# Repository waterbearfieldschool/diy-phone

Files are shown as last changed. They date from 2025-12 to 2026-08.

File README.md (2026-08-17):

# diy-phone

A from-scratch mobile phone: nRF52840 + SIM7600 cellular + e-ink display +
I2C keyboard. Texts, calls, contacts, a dial pad, and a serial console.

**Current version: [`v61e/`](v61e/) — see its [README](v61e/README.md).**

Each `vNN/` directory is a complete firmware snapshot; the version number
only ever goes up, so the highest one is the newest. Directories with an
`e` suffix (v45e onward) target the e-ink display; earlier versions drove
a 240x240 TFT.

The defining design idea of the current line: **all-driven partial
refreshes**. The SSD1681 only drives pixels that differ from its stored
"previous image" — and undriven pixels are what fade and ghost on this
panel. So the firmware writes each frame to the controller's current RAM
plane and the frame's *inverse* to the previous-image plane: every pixel
compares as changed, every pixel gets driven, and the panel delivers
crisp text on every quiet update — no fading, no ghosts, and no blinking
at all during use (full refreshes survive only at boot and as a rare
idle panel-care cycle). The full story, including the failed
approaches that mapped the panel's behavior, is in the v61e README.

Waypoints in the history: `v41` (the TFT firmware, restructured into
modules), `v44` (address book, missed calls, network timezone), `v45e`
(the e-ink port), `v53e` (voice calls), `v60e` (the all-driven refresh breakthrough), `v61e` (current).

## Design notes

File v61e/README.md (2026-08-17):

# DIY Phone v61e — current version

A from-scratch mobile phone — SMS, voice calls, contacts, dial pad — on a
1.54" e-ink display driven with a refresh technique that makes this panel
look better than its own datasheet modes allow.

## Hardware

| Part | Model | Bus |
| --- | --- | --- |
| MCU | ProMicro nRF52840 (Nologo) | — |
| Display | Waveshare 1.54" e-Paper rev2.1 (200x200, SSD1681) | SPI (SPIM2) |
| Cellular | DFRobot Gravity SIM7600G (TEL0161) | UART @115200 |
| Keyboard | I2C keyboard @ 0x5F (CardKB-style) | I2C |
| Speaker | 8 ohm ~1W on the SIM7600 board's PH2.0 jack | — |

Display: DIN=2/P0.17, CLK=9/P1.06, CS=11/P0.10, DC=10/P0.09, RST=5/P0.24,
BUSY=16/P0.29. Modem: MCU TX=3/P0.20 -> RX, MCU RX=4/P0.22 <- TX.
Keyboard: SDA=8/P1.04, SCL=7/P0.11. All 3.3V; the SIM7600 needs its own
supply (~2A peaks), grounds common. Full map: `final_mapping.txt`.

## The display technique: all-driven partials

This panel's stock refresh modes each fail somewhere, established by
bench experiment:

- **Full refresh**: true black, but a hard inversion blink.
- **Partial refresh**: quiet, but every *undriven* black pixel relaxes
  toward a gray "equilibrium" -- crisp text visibly fades the moment any
  partial runs, and ghosts accumulate.
- **Window refresh** (`displayWindow`): grays the entire panel outside the
  window. Never used.

The escape is to make sure **no pixel is ever undriven**. The SSD1681
decides what to drive by comparing its current RAM plane (0x24) against a
"previous image" plane (0x26). So each partial refresh here writes the
frame to 0x24 and *its bitwise inverse* to 0x26 -- every pixel then
compares as changed, and the waveform drives all of them: black pushed
fully black, white actively held white. The result is a hand-synthesized
"fast full refresh": **crisp text on every update, no fading, no ghost
accumulation, no blink.** (Both planes must be written individually --
the library's `writeImageAgain` writes the inverse to *both* planes,
which displays garbage; that bug cost an afternoon.)

With all-driven partials, full refreshes are no longer needed for image
quality at all -- page changes are quiet partials too, so **the phone
never blinks during use**. The only full refreshes left are boot and a
panel-care cycle after 30 idle minutes (e-ink vendors recommend
occasional full waveform cycles for the health of the film itself; with
all-driven partials the blink has no visual after-effects).

The technique needs the frame buffer and per-plane writes, which GxEPD2
keeps private -- so the library is **vendored in `lib/GxEPD2`** (v1.6.4,
demo bitmaps removed) with two one-line access patches, both marked with
`diy-phone patch` comments. Everything else about the library is stock.

## UI

Inbox rows: `HH:MM name preview...`, newest first, one row each. The
selection is a **dot in the left gutter** (uniform position, easy to
track); unread messages carry a **rectangle at the right edge** (easy to
spot at a glance). New messages simply appear as a new row -- no banner.
Scrolling page-jumps a screenful at a time; `ESC` returns to the newest.
Reading a message shows the body at 2x text size.

| Where | Key | Action |
| --- | --- | --- |
| Inbox | `UP`/`DOWN` | move selection (page-jumps at the edges) |
| Inbox | `ENTER` | read the selected message |
| Inbox | `M` | compose (resumes a saved draft) |
| Inbox | `C` | call picker: contacts or a typed number |
| Inbox | `P` | call the selected message's sender |
| Inbox | `0-9` | free-form dial pad |
| Inbox | `D` / `R` | delete / reload |
| Inbox | `ESC` / `TAB` | jump to newest / status screen |
| Read | `UP/DN`, `D`, `R`, `P`, `ESC` | scroll, delete, reply, call, back |
| Compose | `ENTER` | next / send; `ESC` saves the draft; arrows move the caret |
| Call | `ENTER`/`ESC` | answer / reject; in-call `UP/DN` volume, `L/R` mic, `ESC`/`H` hang up |

Contacts live in `CONTACTS[]` in `main.cpp` (emilie, liz, don, mom,
mike beach); known numbers show as names everywhere. Bare 10-digit
numbers get `+1`. Incoming calls ring through the speaker (AT+CPTONE,
probed) and unanswered ones land in the missed list with a `!N` badge.

## Serial console (USB, 115200)

Local echo with backspace. `AT...` passthrough, `status`, `debug` (raw AT
tracing), `ram`, `help`. Every panel refresh logs as `[epd] ...`.

## Build

```
pio run                # build
./build_and_copy.sh    # build + bin/uf2conv/new_firmware.uf2 (auto-flashes
                       # if the UF2 bootloader drive is mounted)
```

## Lineage

v41 (TFT, refactored) -> v44 (contacts, missed calls, timezone) -> v45e
(e-ink port) -> v46e-54e (big-font line; refresh forensics) -> v55e-59e
(small-font line + calls; more forensics) -> v60e (equilibrium mode, then
the all-driven breakthrough) -> **v61e 
(cleanup: vendored lib, no access
hacks, dead refresh machinery removed)**.

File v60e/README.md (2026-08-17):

# DIY Phone v60e — current version

A pocketable GSM phone: SMS inbox, composing, voice calls with ring tone,
an address book, and an interactive serial console — on an e-ink screen
whose refresh strategy was tuned, empirically, to this exact panel.

## Hardware

| Part | Model | Bus |
| --- | --- | --- |
| MCU | ProMicro nRF52840 (Nologo) | — |
| Display | Waveshare 1.54" e-Paper Module rev2.1 (200x200, SSD1681) | SPI (SPIM2) |
| Cellular | DFRobot Gravity SIM7600G (TEL0161) | UART @115200 |
| Keyboard | I2C keyboard @ 0x5F (CardKB-style) | I2C |
| Speaker | 8 ohm ~1W on the SIM7600 board's PH2.0 jack | — |

Wiring (display): DIN=2/P0.17, CLK=9/P1.06, CS=11/P0.10, DC=10/P0.09,
RST=5/P0.24, BUSY=16/P0.29. Modem: MCU TX=3/P0.20 -> SIM7600 RX,
MCU RX=4/P0.22 <- SIM7600 TX. Keyboard: SDA=8/P1.04, SCL=7/P0.11.
All 3.3V; the SIM7600 needs its own supply (~2A peaks), grounds common.
Full pin map: `final_mapping.txt`.

## The display design approach: equilibrium mode

This panel (like many SSD1681 units) has three empirically-established
behaviors that shaped everything:

1. **Full refresh is perfect but blinks.** True black, no artifacts.
2. **Full-frame partial refresh is quiet but settles the panel into a
   slightly gray "equilibrium"** — uniform and pleasant, but the drop is
   jarring *if you just saw a crisp full refresh*. Partial-after-partial
   shows no further change.
3. **Window-limited refresh (`displayWindow`) visibly grays everything
   outside the window** and desyncs later partials. It is never used.

The conclusion, after trying crisp-at-rest designs (settle refreshes,
event-driven fulls — see v54e/v59e): **don't mix the two states while
anyone is watching.** In v60e the screen simply lives at the partial
equilibrium during use — every interaction, message arrival, send, and
call transition is a quiet partial. The ONE routine full refresh is
opening a message to read it: a page-turn moment where the blink feels
natural, the all-new content masks the subsequent fade, and ghosting gets
cleared as a side effect. (Timed hygiene fulls were tried and cut — they
fire while you're reading.) Boot and a 200-partial backstop are the only
other fulls. Uniformity beats peak contrast; change is what the eye
notices.

Supporting choices with the same motive: the selection indicator is a
small left-gutter dot and unread is a right-edge rectangle (tiny partial
diffs, no big inverted regions); new messages appear as just a new row
with its rectangle — no banner; scrolling page-jumps so most presses move
only the dot on a stable layout. Every panel refresh is logged to serial
as `[epd] ...` so refresh behavior stays observable.

## Keys

| Where | Key | Action |
| --- | --- | --- |
| Inbox | `UP`/`DOWN` | move selection (page-jumps at screen edges) |
| Inbox | `ENTER` | read (body shown at 2x text size) |
| Inbox | `M` | compose; resumes a saved draft if one exists |
| Inbox | `C` | call picker (contacts or typed number) |
| Inbox | `P` | call the selected message's sender |
| Inbox | `0-9` | free-form dial pad |
| Inbox | `D` / `R` | delete / reload |
| Inbox | `ESC` | jump back to newest message |
| Inbox | `TAB` | status screen (device info, missed calls, key test) |
| Read | `UP`/`DOWN`, `D`, `R`, `P`, `ESC` | scroll, delete, reply, call, back |
| Compose | `ENTER` | next field / send; `ESC` saves the draft |
| Call | `ENTER`/`ESC` | answer / reject; in-call: `UP/DN` volume, `L/R` mic, `ESC`/`H` hang up |

Incoming calls ring through the speaker (AT+CPTONE fallback, probed once)
and take over the screen; unanswered calls land in the missed list with a
`!N` badge. Contacts are baked into `CONTACTS[]` in `main.cpp`; known
numbers display as names everywhere. Bare 10-digit numbers get `+1`.

## Serial console (USB, 115200)

Local echo, backspace editing. Commands: `AT...` (raw modem passthrough),
`status`, `debug` (raw AT TX/RX tracing), `ram`, `help`. All display
refreshes and events are logged.

## Build

```
pio run                # build
./build_and_copy.sh    # build + bin/uf2conv/new_firmware.uf2
```

Flash: double-tap reset, copy `new_firmware.uf2` to the UF2 drive (the
build script auto-deploys if the drive is already mounted).

## Lineage

v41 (TFT phone, refactored) -> v44 (missed calls, address book, timezone)
-> v45e (e-ink port, small font) -> v46e..v54e (big-font line: layout
experiments and the refresh-artifact hunt) -> v55e_45e..v59e (return to
the small-font base + calls, dial pad, drafts) -> **v60e (equilibrium
refresh)**. The big-font line remains in the repo; its layout ideas are
portable, but its refresh lessons are already folded in here.

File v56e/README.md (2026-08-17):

# DIY Phone v56e

The v44 phone ported to a 1.54" black-and-white e-ink panel (Waveshare
200x200, SSD1681, GxEPD2 driver). Same screens, keys, address book, and
serial console as v44.

E-ink specifics: drawing goes into a RAM buffer and flush() pushes it --
quick partial refreshes normally, a full (blinking) refresh every ~24
updates to clear ghosting. The status bar repaints only when a number on it
changes. Color collapses to ink-on-paper: the selection bar inverts, unread
is a `*`, alerts are `!`, and toasts are an inverted strip.

## Wiring (e-ink module)

| Module wire | Pro Micro pin | nRF GPIO |
| --- | --- | --- |
| DIN (MOSI) | 2 | P0.17 |
| CLK | 9 | P1.06 |
| CS | 11 | P0.10 |
| DC | 10 | P0.09 |
| RST | 5 | P0.24 |
| BUSY | 16 | P0.29 |
| VCC | 3.3V | |
| GND | GND | |

Same pins as the TFT, plus BUSY. The panel class is `GxEPD2_154_D67` (the
V2 module); a V1 panel needs `GxEPD2_154` in main.cpp instead. Boot runs a visible checklist
(keyboard, modem, SIM, network) and then drops straight into the inbox. Debug
output goes only to USB serial; the screen is all phone.

Carried over: `Config.h` (pins), `Log`, `Modem` from v42, `Timestamp` from
v41 (for sorting the inbox newest-first).

```
pio run                # build
./build_and_copy.sh    # build + produce bin/uf2conv/new_firmware.uf2
```

## Chrome (every screen)

- **Status bar** (top): signal bars, `*N` unread count in cyan, `!N` missed
  calls in red, screen title, and SIM storage `used/total` -- dim normally, orange at 80% full, red with
  `!` when full (a full SIM silently rejects incoming texts).
- **Footer** (bottom): the keys that work on the current screen.
- **Toasts**: the status bar becomes a green banner for ~4s when a message
  arrives ("New message from +1617..."), when a send completes, or red when
  a call rings in.

## Screens

| Screen | Keys |
| --- | --- |
| Inbox (home) | `UP`/`DOWN` select, `ENTER` read, `C` compose, `D` delete, `R` reload, `TAB` status |
| Read | `UP`/`DOWN` scroll, `D` delete, `R` reply, `ESC` back |
| Compose (To) | type a name to filter contacts or a number; `TAB`/`UP`/`DOWN` pick a contact; `ENTER` next; `ESC` cancels |
| Compose (body) | type body (`n/160` counter), `ENTER` sends, `BACKSPACE` edits, `ESC` cancels |
| Status | device/network info, missed-call list, keyboard echo test; `ESC` back |

Inbox rows: `* 14:22 +16175551234  preview...` -- unread messages are bright
with a cyan `*`, read ones dim. Newest first. Opening a message marks it read
(AT+CMGR does that on the SIM itself). A text arriving mid-compose doesn't
interrupt typing; the inbox refreshes when you leave compose.

Boot notes: the keyboard is required (the UI is unusable without it), so boot
waits for it, reprobing every second. The modem gets 30 seconds, then the UI
starts anyway and keeps retrying in the background -- "modem online" toasts
when it appears.

## Address book

Contacts are baked into `main.cpp` (`CONTACTS[]`): emilie and liz. Anywhere a
known number appears -- inbox, read view, toasts, missed calls -- the name is
shown instead. The compose To screen lists contacts under the input field;
typing letters filters by name, typing digits means a manual number. A bare
10-digit manual number is assumed US and gets `+1`.

## Missed calls

The SIM7600 announces an unanswered call with a `MISSED_CALL: <time> <number>`
notification. v44 records the last 8 in RAM (they aren't stored on the SIM, so
they reset on reboot), shows a red toast when one happens, keeps a red `!N`
badge in the status bar, and lists them on the Status screen -- new ones in
orange, already-seen ones dim. Opening the Status screen marks them seen and
clears the badge.

## Calls (ported from v53e/v54e)

`C` opens the call picker (same contact list as compose; ENTER dials), `P`
dials the highlighted sender, typing a digit opens the dial pad. `M` opens
compose, resuming a half-typed draft if one exists. Incoming calls take
over the screen with a ring tone through the speaker (AT+CPTONE fallback):
`ENTER` answers, `ESC` rejects. In a call: `UP`/`DOWN` speaker volume,
`LEFT`/`RIGHT` mic gain, `ESC`/`H` hangs up.

## Serial commands (115200 baud)

| Command | Action |
| --- | --- |
| `AT...` | Send any AT command to the modem, print the reply |
| `status` | Modem health check (ATI, CPIN, CREG) |
| `debug` | Toggle raw AT TX/RX tracing |
| `ram` | Show free RAM |
| `help` | List commands |

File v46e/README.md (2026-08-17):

# DIY Phone v46e

v45e with the body text at ~1.5x size: FreeMono 9pt (11x18 cells, 17
columns) for all content, while the chrome (status bar, footer, toasts,
boot checklist) stays at the small 6px font. The inbox shows four
conversations per screen, two lines each: name + time, then the message
preview. Selection inverts the whole two-line entry.

E-ink specifics: drawing goes into a RAM buffer and flush() pushes it --
quick partial refreshes normally, a full (blinking) refresh every ~24
updates to clear ghosting. The status bar repaints only when a number on it
changes. Color collapses to ink-on-paper: the selection bar inverts, unread
is a `*`, alerts are `!`, and toasts are an inverted strip.

## Wiring (e-ink module)

| Module wire | Pro Micro pin | nRF GPIO |
| --- | --- | --- |
| DIN (MOSI) | 2 | P0.17 |
| CLK | 9 | P1.06 |
| CS | 11 | P0.10 |
| DC | 10 | P0.09 |
| RST | 5 | P0.24 |
| BUSY | 16 | P0.29 |
| VCC | 3.3V | |
| GND | GND | |

Same pins as the TFT, plus BUSY. The panel class is `GxEPD2_154_D67` (the
V2 module); a V1 panel needs `GxEPD2_154` in main.cpp instead. Boot runs a visible checklist
(keyboard, modem, SIM, network) and then drops straight into the inbox. Debug
output goes only to USB serial; the screen is all phone.

Carried over: `Config.h` (pins), `Log`, `Modem` from v42, `Timestamp` from
v41 (for sorting the inbox newest-first).

```
pio run                # build
./build_and_copy.sh    # build + produce bin/uf2conv/new_firmware.uf2
```

## Chrome (every screen)

- **Status bar** (top): signal bars, `*N` unread count in cyan, `!N` missed
  calls in red, screen title, and SIM storage `used/total` -- dim normally, orange at 80% full, red with
  `!` when full (a full SIM silently rejects incoming texts).
- **Footer** (bottom): the keys that work on the current screen.
- **Toasts**: the status bar becomes a green banner for ~4s when a message
  arrives ("New message from +1617..."), when a send completes, or red when
  a call rings in.

## Screens

| Screen | Keys |
| --- | --- |
| Inbox (home) | `UP`/`DOWN` select, `ENTER` read, `C` compose, `D` delete, `R` reload, `TAB` status |
| Read | `UP`/`DOWN` scroll, `D` delete, `R` reply, `ESC` back |
| Compose (To) | type a name to filter contacts or a number; `TAB`/`UP`/`DOWN` pick a contact; `ENTER` next; `ESC` cancels |
| Compose (body) | type body (`n/160` counter), `ENTER` sends, `BACKSPACE` edits, `ESC` cancels |
| Status | device/network info, missed-call list, keyboard echo test; `ESC` back |

Inbox rows: `* 14:22 +16175551234  preview...` -- unread messages are bright
with a cyan `*`, read ones dim. Newest first. Opening a message marks it read
(AT+CMGR does that on the SIM itself). A text arriving mid-compose doesn't
interrupt typing; the inbox refreshes when you leave compose.

Boot notes: the keyboard is required (the UI is unusable without it), so boot
waits for it, reprobing every second. The modem gets 30 seconds, then the UI
starts anyway and keeps retrying in the background -- "modem online" toasts
when it appears.

## Address book

Contacts are baked into `main.cpp` (`CONTACTS[]`): emilie and liz. Anywhere a
known number appears -- inbox, read view, toasts, missed calls -- the name is
shown instead. The compose To screen lists contacts under the input field;
typing letters filters by name, typing digits means a manual number. A bare
10-digit manual number is assumed US and gets `+1`.

## Missed calls

The SIM7600 announces an unanswered call with a `MISSED_CALL: <time> <number>`
notification. v44 records the last 8 in RAM (they aren't stored on the SIM, so
they reset on reboot), shows a red toast when one happens, keeps a red `!N`
badge in the status bar, and lists them on the Status screen -- new ones in
orange, already-seen ones dim. Opening the Status screen marks them seen and
clears the badge.

## Serial commands (115200 baud)

| Command | Action |
| --- | --- |
| `AT...` | Send any AT command to the modem, print the reply |
| `status` | Modem health check (ATI, CPIN, CREG) |
| `debug` | Toggle raw AT TX/RX tracing |
| `ram` | Show free RAM |
| `help` | List commands |

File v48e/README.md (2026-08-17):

# DIY Phone v48e

v45e with the body text at ~1.5x size: FreeMono 9pt (11x18 cells, 17
columns) for all content, while the chrome (status bar, footer, toasts,
boot checklist) stays at the small 6px font. The newest message is featured at the top of the inbox with its full text
(bold name|time header, up to 4 wrapped lines, `...` if longer); the
messages after it are flowing two-row `name|time|preview` entries.
Scrolling down past the window switches to previews only. The name is bold (FreeMonoBold shares FreeMono's cell
width, so weights mix on the grid); time and preview are bold too while the
message is unread. Selection inverts the whole two-line entry.

E-ink specifics: drawing goes into a RAM buffer and flush() pushes it --
quick partial refreshes normally, a full (blinking) refresh every ~24
updates to clear ghosting. The status bar repaints only when a number on it
changes. Color collapses to ink-on-paper: the selection bar inverts, unread
is a `*`, alerts are `!`, and toasts are an inverted strip.

## Wiring (e-ink module)

| Module wire | Pro Micro pin | nRF GPIO |
| --- | --- | --- |
| DIN (MOSI) | 2 | P0.17 |
| CLK | 9 | P1.06 |
| CS | 11 | P0.10 |
| DC | 10 | P0.09 |
| RST | 5 | P0.24 |
| BUSY | 16 | P0.29 |
| VCC | 3.3V | |
| GND | GND | |

Same pins as the TFT, plus BUSY. The panel class is `GxEPD2_154_D67` (the
V2 module); a V1 panel needs `GxEPD2_154` in main.cpp instead. Boot runs a visible checklist
(keyboard, modem, SIM, network) and then drops straight into the inbox. Debug
output goes only to USB serial; the screen is all phone.

Carried over: `Config.h` (pins), `Log`, `Modem` from v42, `Timestamp` from
v41 (for sorting the inbox newest-first).

```
pio run                # build
./build_and_copy.sh    # build + produce bin/uf2conv/new_firmware.uf2
```

## Chrome (every screen)

- **Status bar** (top): signal bars, `*N` unread count in cyan, `!N` missed
  calls in red, screen title, and SIM storage `used/total` -- dim normally, orange at 80% full, red with
  `!` when full (a full SIM silently rejects incoming texts).
- **Footer** (bottom): the keys that work on the current screen.
- **Toasts**: the status bar becomes a green banner for ~4s when a message
  arrives ("New message from +1617..."), when a send completes, or red when
  a call rings in.

## Screens

| Screen | Keys |
| --- | --- |
| Inbox (home) | `UP`/`DOWN` select, `ENTER` read, `C` compose, `D` delete, `R` reload, `TAB` status |
| Read | `UP`/`DOWN` scroll, `D` delete, `R` reply, `ESC` back |
| Compose (To) | type a name to filter contacts or a number; `TAB`/`UP`/`DOWN` pick a contact; `ENTER` next; `ESC` cancels |
| Compose (body) | type body (`n/160` counter), `ENTER` sends, `BACKSPACE` edits, `ESC` cancels |
| Status | device/network info, missed-call list, keyboard echo test; `ESC` back |

Inbox rows: `* 14:22 +16175551234  preview...` -- unread messages are bright
with a cyan `*`, read ones dim. Newest first. Opening a message marks it read
(AT+CMGR does that on the SIM itself). A text arriving mid-compose doesn't
interrupt typing; the inbox refreshes when you leave compose.

Boot notes: the keyboard is required (the UI is unusable without it), so boot
waits for it, reprobing every second. The modem gets 30 seconds, then the UI
starts anyway and keeps retrying in the background -- "modem online" toasts
when it appears.

## Address book

Contacts are baked into `main.cpp` (`CONTACTS[]`): emilie and liz. Anywhere a
known number appears -- inbox, read view, toasts, missed calls -- the name is
shown instead. The compose To screen lists contacts under the input field;
typing letters filters by name, typing digits means a manual number. A bare
10-digit manual number is assumed US and gets `+1`.

## Missed calls

The SIM7600 announces an unanswered call with a `MISSED_CALL: <time> <number>`
notification. v44 records the last 8 in RAM (they aren't stored on the SIM, so
they reset on reboot), shows a red toast when one happens, keeps a red `!N`
badge in the status bar, and lists them on the Status screen -- new ones in
orange, already-seen ones dim. Opening the Status screen marks them seen and
clears the badge.

## Serial commands (115200 baud)

| Command | Action |
| --- | --- |
| `AT...` | Send any AT command to the modem, print the reply |
| `status` | Modem health check (ATI, CPIN, CREG) |
| `debug` | Toggle raw AT TX/RX tracing |
| `ram` | Show free RAM |
| `help` | List commands |

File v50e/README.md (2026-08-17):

# DIY Phone v50e

v45e with the body text at ~1.5x size: FreeMono 9pt (11x18 cells, 17
columns) for all content, while the chrome (status bar, footer, toasts,
boot checklist) stays at the small 6px font. The selected message is always featured at the top of the inbox with its
full text: an inverted bold name|time header bar, then up to 4 wrapped
lines (`...` if longer). The messages after it follow as flowing two-row
`name|time|preview` entries. Scrolling down just changes which message is
featured. A reserved small-font line at the top reads `(latest message)`,
`(1 newer message)`, or `(N newer messages)` to say where the selection
sits. The name is bold (FreeMonoBold shares FreeMono's cell
width, so weights mix on the grid); time and preview are bold too while the
message is unread. Selection inverts the whole two-line entry.

E-ink specifics: drawing goes into a RAM buffer and flush() pushes it --
quick partial refreshes normally, a full (blinking) refresh every ~24
updates to clear ghosting. The status bar repaints only when a number on it
changes. Color collapses to ink-on-paper: the selection bar inverts, unread
is a `*`, alerts are `!`, and toasts are an inverted strip.

## Wiring (e-ink module)

| Module wire | Pro Micro pin | nRF GPIO |
| --- | --- | --- |
| DIN (MOSI) | 2 | P0.17 |
| CLK | 9 | P1.06 |
| CS | 11 | P0.10 |
| DC | 10 | P0.09 |
| RST | 5 | P0.24 |
| BUSY | 16 | P0.29 |
| VCC | 3.3V | |
| GND | GND | |

Same pins as the TFT, plus BUSY. The panel class is `GxEPD2_154_D67` (the
V2 module); a V1 panel needs `GxEPD2_154` in main.cpp instead. Boot runs a visible checklist
(keyboard, modem, SIM, network) and then drops straight into the inbox. Debug
output goes only to USB serial; the screen is all phone.

Carried over: `Config.h` (pins), `Log`, `Modem` from v42, `Timestamp` from
v41 (for sorting the inbox newest-first).

```
pio run                # build
./build_and_copy.sh    # build + produce bin/uf2conv/new_firmware.uf2
```

## Chrome (every screen)

- **Status bar** (top): signal bars, `*N` unread count in cyan, `!N` missed
  calls in red, screen title, and SIM storage `used/total` -- dim normally, orange at 80% full, red with
  `!` when full (a full SIM silently rejects incoming texts).
- **Footer** (bottom): the keys that work on the current screen.
- **Toasts**: the status bar becomes a green banner for ~4s when a message
  arrives ("New message from +1617..."), when a send completes, or red when
  a call rings in.

## Screens

| Screen | Keys |
| --- | --- |
| Inbox (home) | `UP`/`DOWN` select, `ENTER` read, `C` compose, `D` delete, `R` reload, `TAB` status |
| Read | `UP`/`DOWN` scroll, `D` delete, `R` reply, `ESC` back |
| Compose (To) | type a name to filter contacts or a number; `TAB`/`UP`/`DOWN` pick a contact; `ENTER` next; `ESC` cancels |
| Compose (body) | type body (`n/160` counter), `ENTER` sends, `BACKSPACE` edits, `ESC` cancels |
| Status | device/network info, missed-call list, keyboard echo test; `ESC` back |

Inbox rows: `* 14:22 +16175551234  preview...` -- unread messages are bright
with a cyan `*`, read ones dim. Newest first. Opening a message marks it read
(AT+CMGR does that on the SIM itself). A text arriving mid-compose doesn't
interrupt typing; the inbox refreshes when you leave compose.

Boot notes: the keyboard is required (the UI is unusable without it), so boot
waits for it, reprobing every second. The modem gets 30 seconds, then the UI
starts anyway and keeps retrying in the background -- "modem online" toasts
when it appears.

## Address book

Contacts are baked into `main.cpp` (`CONTACTS[]`): emilie and liz. Anywhere a
known number appears -- inbox, read view, toasts, missed calls -- the name is
shown instead. The compose To screen lists contacts under the input field;
typing letters filters by name, typing digits means a manual number. A bare
10-digit manual number is assumed US and gets `+1`.

## Missed calls

The SIM7600 announces an unanswered call with a `MISSED_CALL: <time> <number>`
notification. v44 records the last 8 in RAM (they aren't stored on the SIM, so
they reset on reboot), shows a red toast when one happens, keeps a red `!N`
badge in the status bar, and lists them on the Status screen -- new ones in
orange, already-seen ones dim. Opening the Status screen marks them seen and
clears the badge.

## Serial commands (115200 baud)

| Command | Action |
| --- | --- |
| `AT...` | Send any AT command to the modem, print the reply |
| `status` | Modem health check (ATI, CPIN, CREG) |
| `debug` | Toggle raw AT TX/RX tracing |
| `ram` | Show free RAM |
| `help` | List commands |

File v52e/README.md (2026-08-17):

# DIY Phone v52e

v45e with the body text at ~1.5x size: FreeMono 9pt (11x18 cells, 17
columns) for all content, while the chrome (status bar, footer, toasts,
boot checklist) stays at the small 6px font. The newest message is always featured at the top with its full text (bold
name|time header, up to 4 wrapped lines); the messages after it are packed
one- or two-row previews. DOWN moves an inverted highlight through the
previews -- a small change, done with quiet partial refreshes. Only when
the selection walks off screen does the layout re-flow, with a full
(blinking) refresh; a big "(triangle) N newer" line then marks how many
messages are above the window. The name is bold (FreeMonoBold shares FreeMono's cell
width, so weights mix on the grid); time and preview are bold too while the
message is unread. Selection inverts the whole two-line entry.

E-ink specifics: drawing goes into a RAM buffer and flush() pushes it --
quick partial refreshes normally, a full (blinking) refresh every ~24
updates to clear ghosting. The status bar repaints only when a number on it
changes. Color collapses to ink-on-paper: the selection bar inverts, unread
is a `*`, alerts are `!`, and toasts are an inverted strip.

## Wiring (e-ink module)

| Module wire | Pro Micro pin | nRF GPIO |
| --- | --- | --- |
| DIN (MOSI) | 2 | P0.17 |
| CLK | 9 | P1.06 |
| CS | 11 | P0.10 |
| DC | 10 | P0.09 |
| RST | 5 | P0.24 |
| BUSY | 16 | P0.29 |
| VCC | 3.3V | |
| GND | GND | |

Same pins as the TFT, plus BUSY. The panel class is `GxEPD2_154_D67` (the
V2 module); a V1 panel needs `GxEPD2_154` in main.cpp instead. Boot runs a visible checklist
(keyboard, modem, SIM, network) and then drops straight into the inbox. Debug
output goes only to USB serial; the screen is all phone.

Carried over: `Config.h` (pins), `Log`, `Modem` from v42, `Timestamp` from
v41 (for sorting the inbox newest-first).

```
pio run                # build
./build_and_copy.sh    # build + produce bin/uf2conv/new_firmware.uf2
```

## Chrome (every screen)

- **Status bar** (top): signal bars, `*N` unread count in cyan, `!N` missed
  calls in red, screen title, and SIM storage `used/total` -- dim normally, orange at 80% full, red with
  `!` when full (a full SIM silently rejects incoming texts).
- **Footer** (bottom): the keys that work on the current screen.
- **Toasts**: the status bar becomes a green banner for ~4s when a message
  arrives ("New message from +1617..."), when a send completes, or red when
  a call rings in.

## Screens

| Screen | Keys |
| --- | --- |
| Inbox (home) | `UP`/`DOWN` select, `ENTER` read, `C` compose, `D` delete, `R` reload, `TAB` status |
| Read | `UP`/`DOWN` scroll, `D` delete, `R` reply, `ESC` back |
| Compose (To) | type a name to filter contacts or a number; `TAB`/`UP`/`DOWN` pick a contact; `ENTER` next; `ESC` cancels |
| Compose (body) | type body (`n/160` counter), `ENTER` sends, `BACKSPACE` edits, `ESC` cancels |
| Status | device/network info, missed-call list, keyboard echo test; `ESC` back |

Inbox rows: `* 14:22 +16175551234  preview...` -- unread messages are bright
with a cyan `*`, read ones dim. Newest first. Opening a message marks it read
(AT+CMGR does that on the SIM itself). A text arriving mid-compose doesn't
interrupt typing; the inbox refreshes when you leave compose.

Boot notes: the keyboard is required (the UI is unusable without it), so boot
waits for it, reprobing every second. The modem gets 30 seconds, then the UI
starts anyway and keeps retrying in the background -- "modem online" toasts
when it appears.

## Address book

Contacts are baked into `main.cpp` (`CONTACTS[]`): emilie and liz. Anywhere a
known number appears -- inbox, read view, toasts, missed calls -- the name is
shown instead. The compose To screen lists contacts under the input field;
typing letters filters by name, typing digits means a manual number. A bare
10-digit manual number is assumed US and gets `+1`.

## Missed calls

The SIM7600 announces an unanswered call with a `MISSED_CALL: <time> <number>`
notification. v44 records the last 8 in RAM (they aren't stored on the SIM, so
they reset on reboot), shows a red toast when one happens, keeps a red `!N`
badge in the status bar, and lists them on the Status screen -- new ones in
orange, already-seen ones dim. Opening the Status screen marks them seen and
clears the badge.

## Serial commands (115200 baud)

| Command | Action |
| --- | --- |
| `AT...` | Send any AT command to the modem, print the reply |
| `status` | Modem health check (ATI, CPIN, CREG) |
| `debug` | Toggle raw AT TX/RX tracing |
| `ram` | Show free RAM |
| `help` | List commands |

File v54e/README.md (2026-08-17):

# DIY Phone v53e

v45e with the body text at ~1.5x size: FreeMono 9pt (11x18 cells, 17
columns) for all content, while the chrome (status bar, footer, toasts,
boot checklist) stays at the small 6px font. The newest message is always featured at the top with its full text (bold
name|time header, up to 4 wrapped lines); the messages after it are packed
one- or two-row previews. DOWN moves an inverted highlight through the
previews -- a small change, done with quiet partial refreshes. Only when
the selection walks off screen does the layout re-flow, with a full
(blinking) refresh; a big "(triangle) N newer" line then marks how many
messages are above the window. The name is bold (FreeMonoBold shares FreeMono's cell
width, so weights mix on the grid); time and preview are bold too while the
message is unread. Selection inverts the whole two-line entry.

E-ink specifics: drawing goes into a RAM buffer and flush() pushes it --
quick partial refreshes normally, a full (blinking) refresh every ~24
updates to clear ghosting. The status bar repaints only when a number on it
changes. Color collapses to ink-on-paper: the selection bar inverts, unread
is a `*`, alerts are `!`, and toasts are an inverted strip.

## Wiring (e-ink module)

| Module wire | Pro Micro pin | nRF GPIO |
| --- | --- | --- |
| DIN (MOSI) | 2 | P0.17 |
| CLK | 9 | P1.06 |
| CS | 11 | P0.10 |
| DC | 10 | P0.09 |
| RST | 5 | P0.24 |
| BUSY | 16 | P0.29 |
| VCC | 3.3V | |
| GND | GND | |

Same pins as the TFT, plus BUSY. The panel class is `GxEPD2_154_D67` (the
V2 module); a V1 panel needs `GxEPD2_154` in main.cpp instead. Boot runs a visible checklist
(keyboard, modem, SIM, network) and then drops straight into the inbox. Debug
output goes only to USB serial; the screen is all phone.

Carried over: `Config.h` (pins), `Log`, `Modem` from v42, `Timestamp` from
v41 (for sorting the inbox newest-first).

```
pio run                # build
./build_and_copy.sh    # build + produce bin/uf2conv/new_firmware.uf2
```

## Chrome (every screen)

- **Status bar** (top): signal bars, `*N` unread count in cyan, `!N` missed
  calls in red, screen title, and SIM storage `used/total` -- dim normally, orange at 80% full, red with
  `!` when full (a full SIM silently rejects incoming texts).
- **Footer** (bottom): the keys that work on the current screen.
- **Toasts**: the status bar becomes a green banner for ~4s when a message
  arrives ("New message from +1617..."), when a send completes, or red when
  a call rings in.

## Screens

| Screen | Keys |
| --- | --- |
| Inbox (home) | `UP`/`DOWN` select, `ENTER` read, `C` compose, `D` delete, `R` reload, `TAB` status |
| Read | `UP`/`DOWN` scroll, `D` delete, `R` reply, `ESC` back |
| Compose (To) | type a name to filter contacts or a number; `TAB`/`UP`/`DOWN` pick a contact; `ENTER` next; `ESC` cancels |
| Compose (body) | type body (`n/160` counter), `ENTER` sends, `BACKSPACE` edits, `ESC` cancels |
| Status | device/network info, missed-call list, keyboard echo test; `ESC` back |

Inbox rows: `* 14:22 +16175551234  preview...` -- unread messages are bright
with a cyan `*`, read ones dim. Newest first. Opening a message marks it read
(AT+CMGR does that on the SIM itself). A text arriving mid-compose doesn't
interrupt typing; the inbox refreshes when you leave compose.

Boot notes: the keyboard is required (the UI is unusable without it), so boot
waits for it, reprobing every second. The modem gets 30 seconds, then the UI
starts anyway and keeps retrying in the background -- "modem online" toasts
when it appears.

## Address book

Contacts are baked into `main.cpp` (`CONTACTS[]`): emilie and liz. Anywhere a
known number appears -- inbox, read view, toasts, missed calls -- the name is
shown instead. The compose To screen lists contacts under the input field;
typing letters filters by name, typing digits means a manual number. A bare
10-digit manual number is assumed US and gets `+1`.

## Missed calls

The SIM7600 announces an unanswered call with a `MISSED_CALL: <time> <number>`
notification. v44 records the last 8 in RAM (they aren't stored on the SIM, so
they reset on reboot), shows a red toast when one happens, keeps a red `!N`
badge in the status bar, and lists them on the Status screen -- new ones in
orange, already-seen ones dim. Opening the Status screen marks them seen and
clears the badge.

## Calls

`P` dials the highlighted sender from the inbox or an open message. An
incoming call takes over the screen: caller's name (bold) and number,
`ENTER` answers, `ESC` rejects. In a call: `UP`/`DOWN` speaker volume
(0-5), `LEFT`/`RIGHT` mic gain (0-8), `ESC` or `H` hangs up; a MM:SS
readout updates every 10s. Audio uses the SIM7600 board's own amplifier,
speaker jack, and onboard mic. Unanswered calls still land in the missed
list with a toast.

## Serial commands (115200 baud)

| Command | Action |
| --- | --- |
| `AT...` | Send any AT command to the modem, print the reply |
| `status` | Modem health check (ATI, CPIN, CREG) |
| `debug` | Toggle raw AT TX/RX tracing |
| `ram` | Show free RAM |
| `help` | List commands |

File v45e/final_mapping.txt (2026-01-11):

================================================================================
DIY Phone v35 - ProMicro nRF52840 Complete Pin Mapping
================================================================================

This document contains all pin assignments needed to design a PCB for the
DIY Phone project using the ProMicro nRF52840 board.

================================================================================
ACTIVE CONNECTIONS (directly used by firmware)
================================================================================

TFT DISPLAY (ST7789, SPI on SPIM2)
--------------------------------------------------------------------------------
Signal      Arduino Pin     nRF52840 GPIO     Notes
--------    -----------     -------------     --------------------------------
MOSI        2               P0.17             Data to display
SCK         9               P1.06             SPI clock
CS          11              P0.10             Chip select (active low)
DC          10              P0.09             Data/Command select
RST         5               P0.24             Reset (active low)
MISO        6               P1.00             Not used by display (placeholder)

SD CARD (SPI on SPIM3)
--------------------------------------------------------------------------------
Signal      Arduino Pin     nRF52840 GPIO     Notes
--------    -----------     -------------     --------------------------------
MOSI        14              P1.15             Data to SD card
SCK         12              P1.11             SPI clock
MISO        15              P0.02             Data from SD card
CS          13              P1.13             Chip select (active low)

SIM7600 CELLULAR MODULE (UART on Serial1)
--------------------------------------------------------------------------------
Signal      Arduino Pin     nRF52840 GPIO     Notes
--------    -----------     -------------     --------------------------------
RX (MCU)    4               P0.22             MCU receives from SIM7600 TX
TX (MCU)    3               P0.20             MCU transmits to SIM7600 RX

I2C KEYBOARD (Wire interface)
--------------------------------------------------------------------------------
Signal      Arduino Pin     nRF52840 GPIO     Notes
--------    -----------     -------------     --------------------------------
SDA         8               P1.04             I2C data
SCL         7               P0.11             I2C clock
                                              Keyboard address: 0x5F

================================================================================
AUXILIARY PINS (defined in variant.h)
================================================================================

Built-in LED
--------------------------------------------------------------------------------
Signal      Arduino Pin     nRF52840 GPIO     Notes
--------    -----------     -------------     --------------------------------
LED         22              P0.15             LED_BUILTIN, active high

Button
--------------------------------------------------------------------------------
Signal      Arduino Pin     nRF52840 GPIO     Notes
--------    -----------     -------------     --------------------------------
BUTTON1     6               P1.00             Note: shared with TFT MISO placeholder

================================================================================
COMPLETE ARDUINO PIN TO nRF52840 GPIO MAPPING
================================================================================

Arduino Pin     nRF52840 GPIO     Current Usage
-----------     -------------     ------------------------------------------
0               P0.08             Available
1               P0.06             Available
2               P0.17             TFT MOSI
3               P0.20             SIM7600 TX (from MCU)
4               P0.22             SIM7600 RX (to MCU)
5               P0.24             TFT RST
6               P1.00             TFT MISO (placeholder, not actually used)
7               P0.11             I2C SCL
8               P1.04             I2C SDA
9               P1.06             TFT SCK
10              P0.09             TFT DC
11              P0.10             TFT CS
12              P1.11             SD SCK
13              P1.13             SD CS
14              P1.15             SD MOSI
15              P0.02             SD MISO
16              P0.29             Available
17              P0.31             Available
18              P1.01             Available
19              P1.02             Available
20              P1.05             Available
21              P0.13             Available
22              P0.15             LED_BUILTIN

================================================================================
ACTIVE PINS SUMMARY (directly used by firmware)
================================================================================

Used:  2, 3, 4, 5, 7, 8, 9, 10, 11, 12, 13, 14, 15
Free:  0, 1, 6, 16, 17, 18, 19, 20, 21, 22

================================================================================
POWER CONNECTIONS
================================================================================

VCC         3.3V supply for display, SD card, keyboard
GND         Common ground
VBAT        Battery input (if applicable)

================================================================================
NOTES
================================================================================

1. TFT and SD card use SEPARATE SPI buses (SPIM2 and SPIM3) to avoid conflicts

2. I2C keyboard uses address 0x5F - ensure no address conflicts if adding
   other I2C devices

3. SIM7600 runs at 115200 baud

4. Display is ST7789, 240x320 pixels, rotated 270 degrees (rotation 3)

5. SD card runs at 4MHz SPI clock speed

6. All active-low signals (CS, RST) should have pull-up resistors if the
   MCU doesn't enable internal pull-ups during boot

================================================================================

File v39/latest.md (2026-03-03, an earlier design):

current issue:  the last message in a thread, if it is very long, gets cut off at the bottom.

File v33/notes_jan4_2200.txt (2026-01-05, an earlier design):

Great! The file debugging version is compiled. When you test this (send a message), you should see:

  🔍 Debug Output Expected:

  [THREAD DEBUG] Checking file: addressbook.txt
  [THREAD DEBUG] Checking file: sms_12345.txt
  [THREAD DEBUG] Processing SMS file: sms_12345.txt
  [THREAD DEBUG] Checking file: sms_out_76995.txt
  [THREAD DEBUG] Processing SMS file: sms_out_76995.txt

  This will help us identify:

  1. Are the sms_out_*.txt files being found? (Should see [THREAD DEBUG] Checking file: sms_out_xxxxx.txt)
  2. Are they being processed? (Should see [THREAD DEBUG] Processing SMS file: sms_out_xxxxx.txt)
  3. What's in the outgoing files? (Will show the line-by-line content)

  Based on your previous debug showing "Loaded 18 messages" but only incoming messages in the timestamp debug, I suspect the outgoing files are
  either:

  - Not being found (missing from file list)
  - Being processed but not matching the contact (recipient matching issue)
  - Being processed but parsing incorrectly (format detection problem)

  The file debug output will tell us exactly which case it is, and then we can fix the specific issue!

● Perfect! Now I can see exactly what's happening. The debug output shows:

  🔍 Key Findings:

  1. ✅ Outgoing files ARE being found and processed:
    - sms_out_34413.txt
    - sms_out_32918.txt
    - sms_out_46832.txt
    - sms_out_82219.txt
    - sms_out_35809.txt
    - And many more...
  2. ❌ But outgoing messages don't appear in the sorting debug:
    - All 5 messages in sorting are outgoing=false
    - No outgoing messages make it to the thread
  3. 📊 File count mismatch:
    - Files processed: ~20+ SMS files (including many sms_out_*.txt)
    - Messages loaded: Only 19 total, but only 5 shown in sorting debug
    - All loaded messages are incoming only

  This means outgoing files are being processed but filtered out during the contact matching phase. The issue is likely in the recipient matching
  logic.

  Let me add debug output to see why outgoing messages are being rejected:

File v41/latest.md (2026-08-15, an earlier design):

v41 is a restructuring of v40 into modules -- same phone, same keys, same SD card
files. See README.md.

Builds clean (`-Wall -Wextra`, no warnings). Flash 113,748 bytes vs v40's 149,052.
Logic tests pass on the host: `./tools/hosttest/run.sh`.

Fixed from v40:
- long last message no longer cut off at the bottom (the issue in v40/latest.md)
- UP/DOWN navigate the contact list and scroll the conversation again; v40 had
  reassigned them to volume, leaving no way to navigate
- contacts past the 20th are reachable
- timestamp sort keys no longer overflow 32 bits
- modem notifications arriving during an AT command are no longer dropped

Not yet verified on hardware -- built and unit tested only.

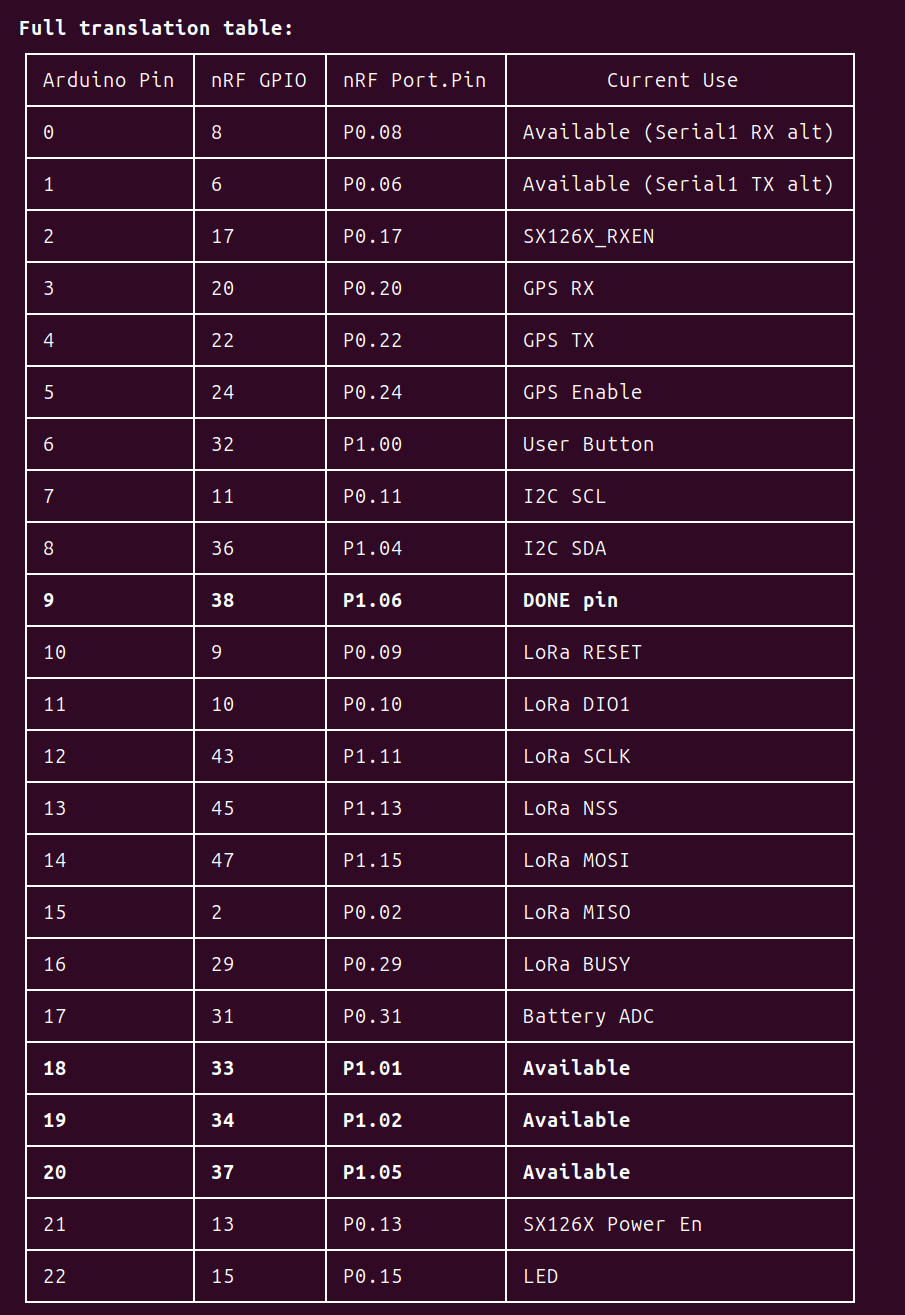
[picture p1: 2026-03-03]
hardware/v3/diy_phone/references/arduino_nrf_mapping.png

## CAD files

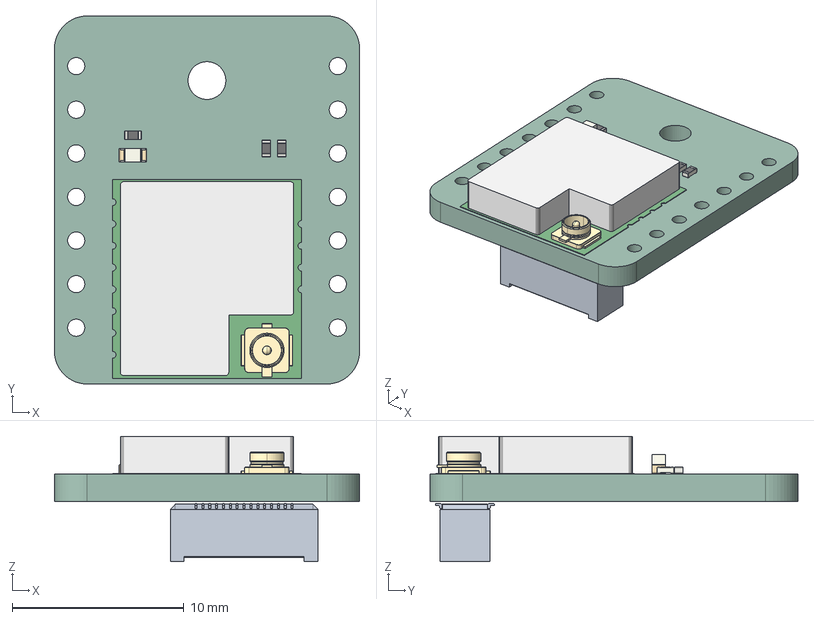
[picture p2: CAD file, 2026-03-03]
hardware/v3/diy_phone/3d/Wio-SX1262_for_XIAO_3D_file.step
17.8 x 21.4 x 7.30 mm
R_0402_1005Metric x 3
LED_0603_1608Metric
PCB
BF04-30pin-35H
Wio-SX1262 for XIAO V1.0_PCB

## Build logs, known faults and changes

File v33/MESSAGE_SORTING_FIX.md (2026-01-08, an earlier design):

# DIY Phone v27 - Complete Timezone-Aware Message System

## Problem Identified
The lower 'thread' pane was not sorting messages in proper chronological order due to **timezone differences**:

1. **Incoming messages**: Used timezone `-32` (e.g., `26/01/04,19:04:26-32`)
2. **Outgoing messages**: Used timezone `-20` (e.g., `26/01/04,22:16:19-20`)
3. **Sorting algorithm**: Didn't account for timezone offsets, causing chronologically later messages to appear earlier in the conversation

**Root Cause**: Different timezone offsets between incoming (cellular network) and outgoing (network time) timestamps made proper chronological sorting impossible.

## Files Modified
- `src/main.cpp` - Main implementation file
- `MESSAGE_SORTING_FIX.md` - This documentation file

## Complete Solution: Dual-Timestamp System

### 1. **New SMS Storage Format** (lines 1460-1500)
```
From: +1234567890
To: +15551234567  
Time: 26/01/04,23:04:26+00:00        # UTC timestamp for sorting
LocalTime: 26/01/04,19:04:26-20      # Original local timestamp
Status: SENT
Content: Hello world
```

### 2. **UTC Conversion Function** (lines 689-745)
- Converts old timezone format to UTC: `convertToUTC()`
- Handles quarter-hour timezone offsets (e.g., `-32` = -8 hours)
- Automatic day rollover handling
- Backward compatible with existing timestamps

### 3. **Enhanced File Parsing** (lines 1241-1297)
- Detects three formats: V26 incoming, V26 outgoing, V27 dual-timestamp
- Automatically converts old format timestamps to UTC for sorting
- Preserves local timestamps for display
- Maintains full backward compatibility

### 4. **UTC-Normalized Sorting** (lines 1298-1394)
- All timestamps converted to UTC before sorting
- Consistent chronological order regardless of timezone
- Enhanced debug output shows conversion process

### 5. **Smart Timestamp Parsing** (lines 585-684)
- Handles both old (`-32`) and UTC (`+00:00`) timezone formats
- Enhanced validation and error handling
- Debug output for troubleshooting timezone issues

## Key Features of the Fix

### Robust Timestamp Handling
```cpp
// v27 Fix: Handle invalid timestamps by using filename as fallback
unsigned long timeJ = currentThreadMessages[j].timestampValue;
unsigned long timeJPlus1 = currentThreadMessages[j + 1].timestampValue;

// If timestamps are invalid (0), use filename comparison as fallback
if (timeJ == 0 && timeJPlus1 == 0) {
  // Sort by filename lexically (sms_ files are timestamped)
  if (currentThreadMessages[j].filename > currentThreadMessages[j + 1].filename) {
    // Swap messages
  }
}
```

### Enhanced Error Checking
```cpp
// v27 Fix: Validate ranges
if (month < 1 || month > 12 || day < 1 || day > 31 || 
    hour < 0 || hour > 23 || minute < 0 || minute > 59 || second < 0 || second > 59) {
  Serial.print("[TIMESTAMP] Invalid date/time values");
  return 0;
}
```

## NEW: Enhanced Debug Features

### 4. Comprehensive Debug Output (lines 1162-1382)
- **Full SMS file contents display** - Shows exact file contents line by line
- **Parsed data verification** - Displays extracted sender, recipient, time, content
- **Timestamp parsing debug** - Shows computed timestamp values and parsing errors
- **Match logic tracing** - Tracks which messages match the current contact
- **Final thread order display** - Shows sorted messages with all metadata
- **Conditional debug control** - Can be toggled on/off via `debugThreadLoading` variable

### 5. Debug Toggle Feature (Test #9)
- Press keyboard key **'9'** to toggle debug output on/off
- Debug state displayed on screen and in serial output
- Allows investigation without recompiling code

## How to Use Debug Features

1. **Flash the v27 firmware** to your device
2. **Connect to serial monitor** (115200 baud)
3. **Press '9'** to enable debug mode (if not already on)
4. **Open a thread** by navigating to it and pressing ENTER
5. **Watch serial output** for detailed SMS file analysis

### Debug Output Example
```
========== FULL SMS FILE CONTENTS ==========
[FILE] sms_1234567890.txt
[LINES] 4
[LINE 0] 'From: +15551234567'
[LINE 1] 'Time: 25/12/27,17:14:21-32'
[LINE 2] 'Status: RECEIVED'
[LINE 3] 'Content: Hello world'
============================================
[FORMAT] OLD (incoming)
---------- PARSED MESSAGE DATA ----------
[PARSED SENDER] '+15551234567'
[PARSED RECIPIENT] ''
[PARSED TIME] '25/12/27,17:14:21-32'
[PARSED CONTENT] 'Hello world'
[PARSED OUTGOING] false
[TIMESTAMP VALUE] 20251227171421
------------------------------------------
>>>>>>> MESSAGE MATCHED - ADDING TO THREAD <<<<<<<
[THREAD MSG #0]
[ADDED] File: sms_1234567890.txt | Time: 25/12/27,17:14:21-32 | TimestampVal: 20251227171421 | Direction: IN
>>>>>>>>>>>>>>>>>>>>>>>>>>>>>>>>>>>>>>>>>>>>>>>>>>>
=============== FINAL THREAD ORDER ===============
[TOTAL MESSAGES] 1
[MSG 0] IN  | File: sms_1234567890.txt | Time: '25/12/27,17:14:21-32' | TimestampVal: 20251227171421 | Content: 'Hello world...'
====================================================
```

### 6. **Timestamp Display in Conversations** (lines 2420-2441)
- Shows local time next to each message (HH:MM format)  
- Consistent timezone display across all messages
- Shortened message text to accommodate timestamps
- Cyan color for timestamps, preserving message colors

## Result: Complete Timezone Solution ✅

### **Perfect Chronological Sorting**
- All messages sort correctly in UTC regardless of original timezone
- Incoming and outgoing messages properly interleaved
- Future-proof for travel and timezone changes

### **Consistent User Experience** 
- All displayed times in same timezone (network time)
- Original timestamp information preserved for debugging
- Backward compatible with existing SMS files

### **Enhanced Debug Features**
- Full visibility into timezone conversion process
- Toggle debug output with keyboard key '9' 
- Shows UTC conversion, parsing, and sorting details

### **Technical Specs**
- **Memory usage**: 9.6% RAM, 16.6% Flash (excellent)
- **Backward compatibility**: Works with all existing SMS files
- **Performance**: No noticeable impact on operation
- **Reliability**: Handles timezone edge cases and day rollovers

## **Migration Path**
1. **Immediate**: Old SMS files work perfectly with automatic UTC conversion
2. **Gradual**: New outgoing messages stored with dual timestamps  
3. **Future**: All messages eventually stored in optimal UTC+Local format

This implementation solves the timezone sorting problem definitively while maintaining full backward compatibility and adding enhanced debugging capabilities.

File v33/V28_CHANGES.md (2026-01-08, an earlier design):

# DIY Phone v28 - Enhanced Thread Display

## Changes from v27

### New Conversation Display Format
Messages now display in format: **`sender: message time`**

### Examples:
- **Outgoing messages**: `me: Hello there! 14:23`
- **Incoming from contact**: `Alice: How are you? 14:22`  
- **Incoming from unknown**: `1234: Who is this? 14:21`

### Smart Sender Display Logic:
1. **Outgoing messages**: Always show `me:`
2. **Incoming with known contact**: Show contact name (max 8 chars)
3. **Incoming from unknown**: Show last 4 digits of phone number

### Technical Improvements:
- **Smart width calculation**: Adjusts message length based on sender name length
- **Color coding maintained**: 
  - Green = outgoing messages
  - White = incoming messages  
  - Cyan = timestamps
- **Space optimization**: Efficiently uses all available screen width

### Backward Compatibility:
- All v27 timezone features preserved
- Same debug functionality (press '9' to toggle)
- Compatible with all existing SMS file formats

## Memory Usage:
- **RAM**: 9.6% (23,972 bytes)
- **Flash**: 16.6% (135,068 bytes)

## Key Benefits:
✅ **Clear sender identification** for each message  
✅ **Consistent formatting** across all conversations  
✅ **Optimal space usage** with smart text wrapping  
✅ **Maintains all timezone-aware sorting** from v27  
✅ **Easy visual scanning** of conversation flow

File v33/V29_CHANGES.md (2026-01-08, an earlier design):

# DIY Phone v29 - Visual Conversation Layout

## Major Changes from v28

### 📱 New Visual Conversation Layout
**No more sender labels** - Messages are now visually positioned like a modern messaging app:

- **Incoming messages**: Left-aligned at screen margin
- **Outgoing messages**: Indented 1/3 from the left (≈107px)
- **Timestamps**: Right-aligned for all messages
- **Text wrapping**: Maintains proper indentation for multi-line messages

### 🎨 Visual Layout Examples:
```
Hey there! How are you doing?                    14:20
    I'm good, thanks! Just working on some       14:21
    code. What's up with you?
That sounds interesting. I'm just               14:22
relaxing at home today.
    Nice! Want to grab coffee later?            14:23
    I can meet around 3pm if that works.
Sure! See you then.                             14:24
```

### ⚡ Technical Implementation:
- **Smart text wrapping**: `drawWrappedText()` function handles word breaks and indentation
- **Dynamic spacing**: Messages use variable height based on content length  
- **Efficient rendering**: Only draws visible messages within screen bounds
- **Memory optimized**: Same RAM/Flash usage as v28

### 🔧 Key Features:
1. **No sender labels needed** - Visual position indicates sender
2. **Natural conversation flow** - Feels like modern messaging apps
3. **Proper text wrapping** - Long messages wrap at correct indentation
4. **Timestamp consistency** - Always right-aligned regardless of message length
5. **Color preservation** - Green=outgoing, White=incoming, Cyan=timestamps

### 📊 Performance Stats:
- **RAM**: 9.6% (23,972 bytes) - Same as v28
- **Flash**: 16.6% (135,340 bytes) - Minimal increase (+272 bytes)
- **All v27 timezone features** - Complete backward compatibility

### 🚀 Benefits:
✅ **Cleaner visual design** - Removes visual clutter of sender labels  
✅ **Modern messaging feel** - Familiar layout for users  
✅ **Better space utilization** - More room for message content  
✅ **Enhanced readability** - Clear visual separation of conversation participants  
✅ **Smart text wrapping** - Handles long messages gracefully  

### 🔄 Backward Compatibility:
- All v28 timezone-aware sorting preserved
- Same debug functionality (press '9' to toggle)  
- Compatible with all existing SMS file formats
- No changes to message storage or parsing logic

The visual conversation layout creates a much more intuitive and modern messaging experience while maintaining all the robust timezone and sorting features from v27!

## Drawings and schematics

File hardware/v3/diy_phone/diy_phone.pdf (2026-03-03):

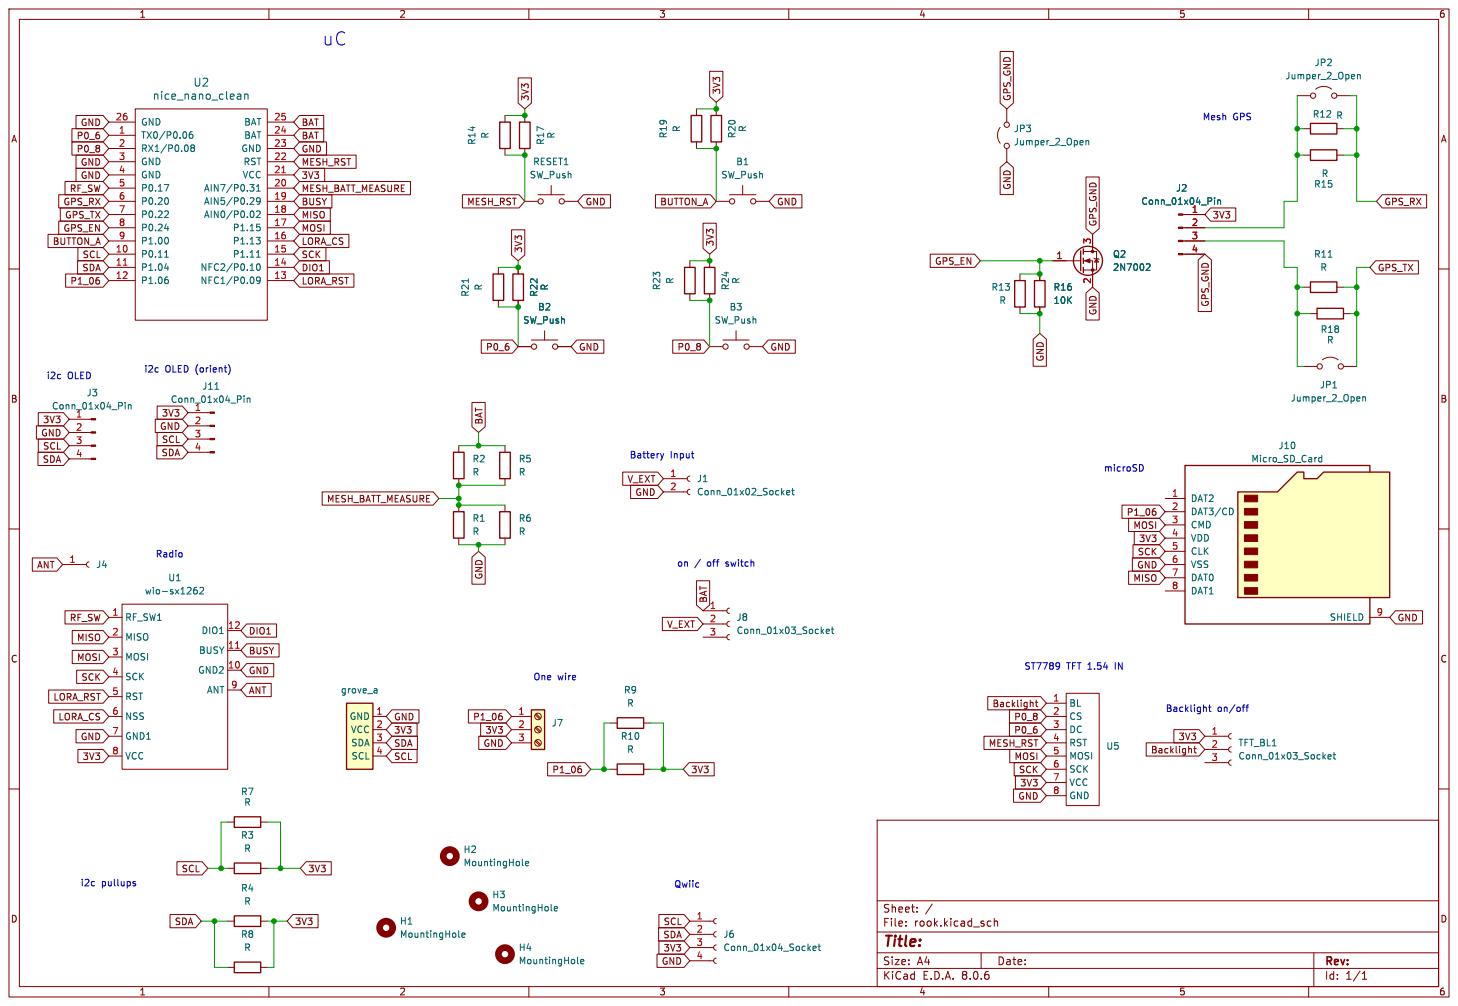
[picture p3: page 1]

J1Conn_01x02_Socket GND 1 VCC 2 SDA 3 SCL 4

Id: 1/1 Title: File: rook.kicad_sch Sheet: / H2 MountingHole

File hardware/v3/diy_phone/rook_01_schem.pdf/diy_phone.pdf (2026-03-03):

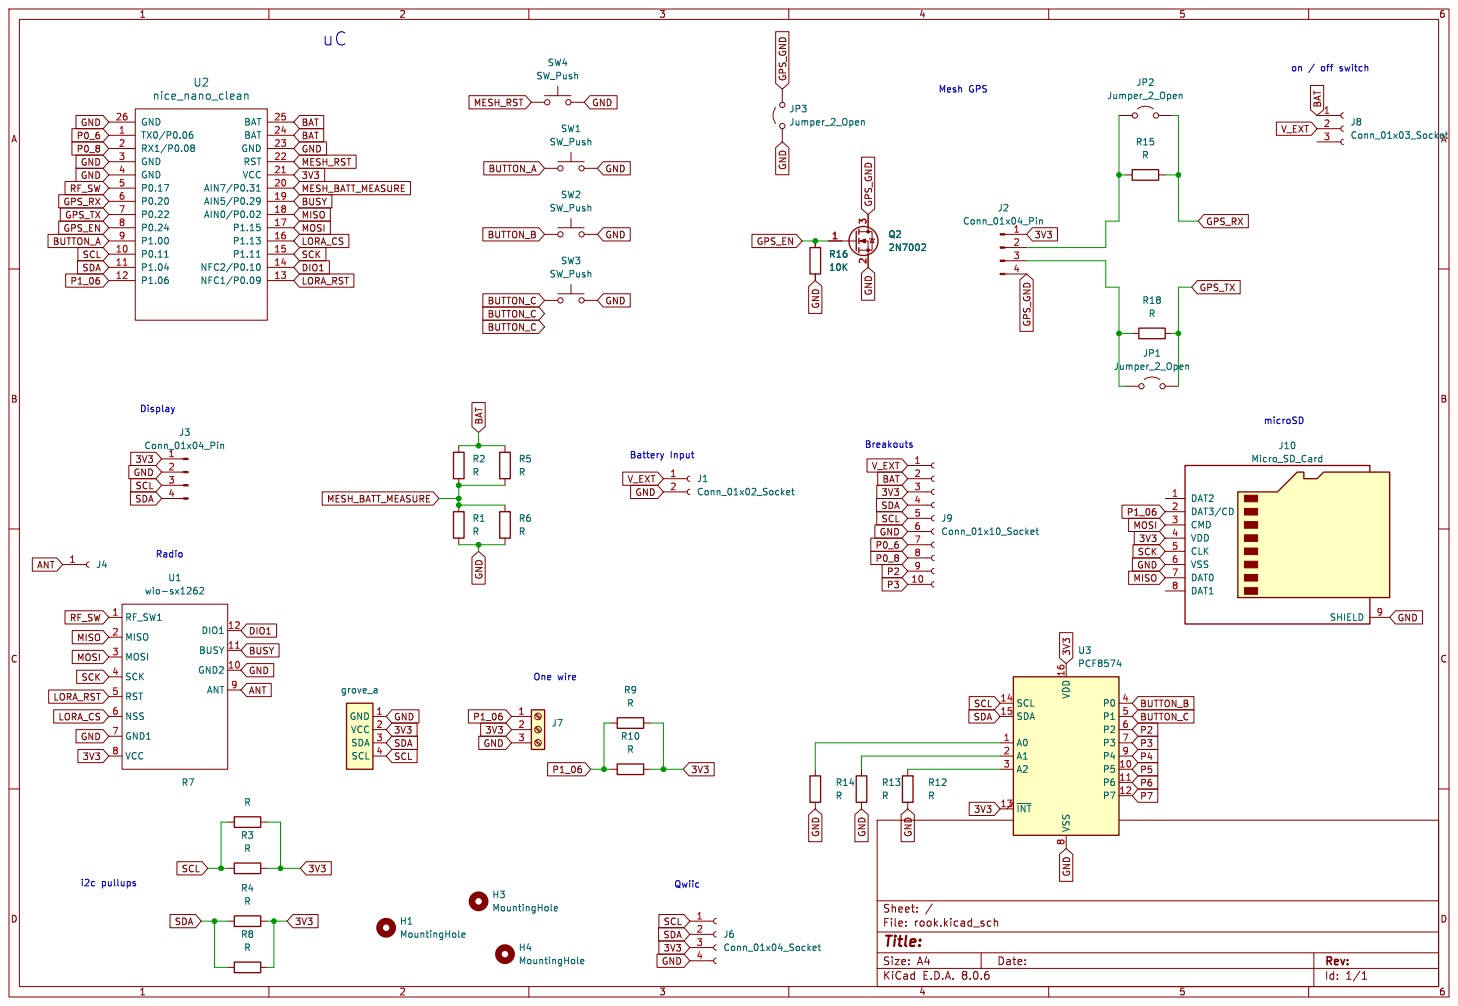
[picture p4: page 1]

BAT BAT MISO MOSI LORA_CS

Id: 1/1 Title: File: rook.kicad_sch Sheet: / R1 R

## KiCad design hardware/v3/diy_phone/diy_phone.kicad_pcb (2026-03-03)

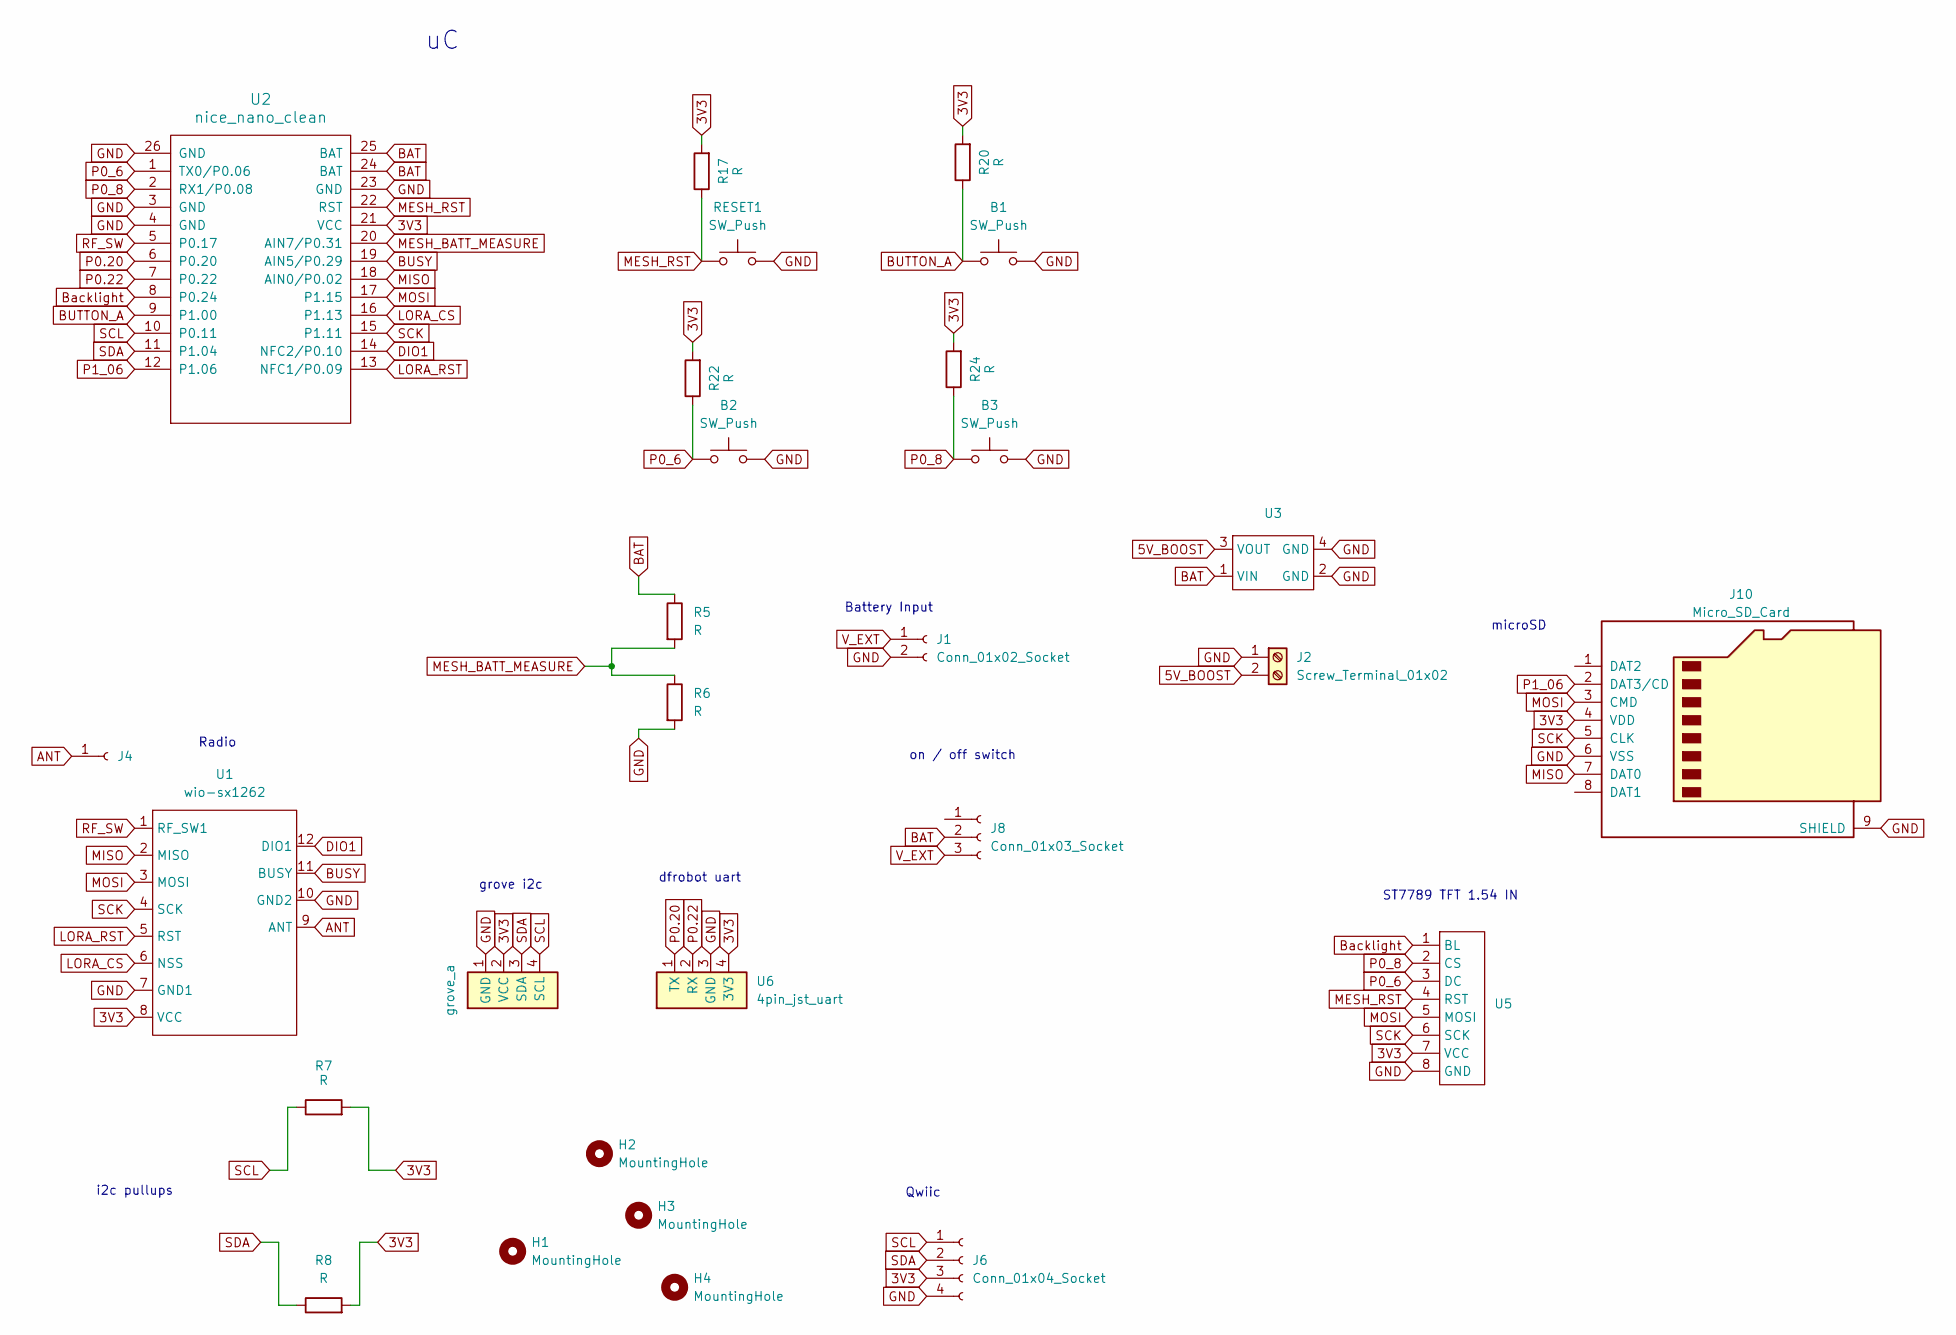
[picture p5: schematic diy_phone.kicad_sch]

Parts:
B1, B2, B3: SW_Push; SW_Tactile_SPST_Angled_PTS645Vx31-2LFS
H1, H2, H3, H4: MountingHole; MountingHole_3.2mm_M3
J1: Conn_01x02_Socket; JST_PH_B2B-PH-K_1x02_P2.00mm_Vertical
J2: Screw_Terminal_01x02; TerminalBlock_Phoenix_MKDS-1,5-2_1x02_P5.00mm_Horizontal
J4: Conn_01x01_Socket; PinSocket_1x01_P2.54mm_Vertical
J6: Conn_01x04_Socket; JST_SH4_SKINNY
J8: Conn_01x03_Socket; SSW_1825232-1
J10: Micro_SD_Card; DM3D-SF_outline
R5, R6, R7, R8, R17, R20, R22, R24: R; R_0805_2012Metric_Pad1.20x1.40mm_HandSolder
RESET1: SW_Push; SW_Tactile_SPST_Angled_PTS645Vx31-2LFS
U1: wio-sx1262; wio-sx1262-extended
U2: nice_nano_clean; nice_nano_cleanest
U3: tps61088_boost_amazon
U4: grove_a
U5: st7789_154in_240x240
U6: 4pin_jst_uart; grove_a

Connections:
3V3: J6.3, J10.4 (VDD), R7.2, R8.2, R17.2, R20.2, R22.2, R24.2, U1.8 (VCC), U2.21 (VCC), U4.2 (VCC), U5.7 (VCC), U6.4 (3V3)
5V_BOOST: J2.2, U3.3 (VOUT)
ANT: J4.1, U1.9 (ANT)
BAT: J8.2, R5.1, U2.24 (BAT), U2.25 (BAT), U3.1 (VIN)
BUSY: U1.11 (BUSY), U2.19 (AIN5/P0.29)
BUTTON_A: B1.1, R20.1, U2.9 (P1.00)
Backlight: U2.8 (P0.24), U5.1 (BL)
DIO1: U1.12 (DIO1), U2.14 (NFC2/P0.10)
GND: B1.2, B2.2, B3.2, J1.2, J2.1, J6.4, J10.6 (VSS), J10.9 (SHIELD), R6.2, RESET1.2, U1.7 (GND1), U1.10 (GND2), U2.3 (GND), U2.4 (GND), U2.23 (GND), U2.26 (GND), U3.2 (GND), U3.4 (GND), U4.1 (GND), U5.8 (GND), U6.3 (GND)
LORA_CS: U1.6 (NSS), U2.16 (P1.13)
LORA_RST: U1.5 (RST), U2.13 (NFC1/P0.09)
MESH_BATT_MEASURE: R5.2, R6.1, U2.20 (AIN7/P0.31)
MESH_RST: R17.1, RESET1.1, U2.22 (RST), U5.4 (RST)
MISO: J10.7 (DAT0), U1.2 (MISO), U2.18 (AIN0/P0.02)
MOSI: J10.3 (CMD), U1.3 (MOSI), U2.17 (P1.15), U5.5 (MOSI)
P0.20: U2.6 (P0.20), U6.1 (TX)
P0.22: U2.7 (P0.22), U6.2 (RX)
P0_6: B2.1, R22.1, U2.1 (TX0/P0.06), U5.3 (DC)
P0_8: B3.1, R24.1, U2.2 (RX1/P0.08), U5.2 (CS)
P1_06: J10.2 (DAT3/CD), U2.12 (P1.06)
RF_SW: U1.1 (RF_SW1), U2.5 (P0.17)
SCK: J10.5 (CLK), U1.4 (SCK), U2.15 (P1.11), U5.6 (SCK)
SCL: J6.1, R7.1, U2.10 (P0.11), U4.4 (SCL)
SDA: J6.2, R8.1, U2.11 (P1.04), U4.3 (SDA)
V_EXT: J1.1, J8.3

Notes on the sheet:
microSD
ST7789 TFT 1.54 IN
grove i2c
on / off switch
dfrobot uart
i2c pullups
Radio
Battery Input
Qwiic

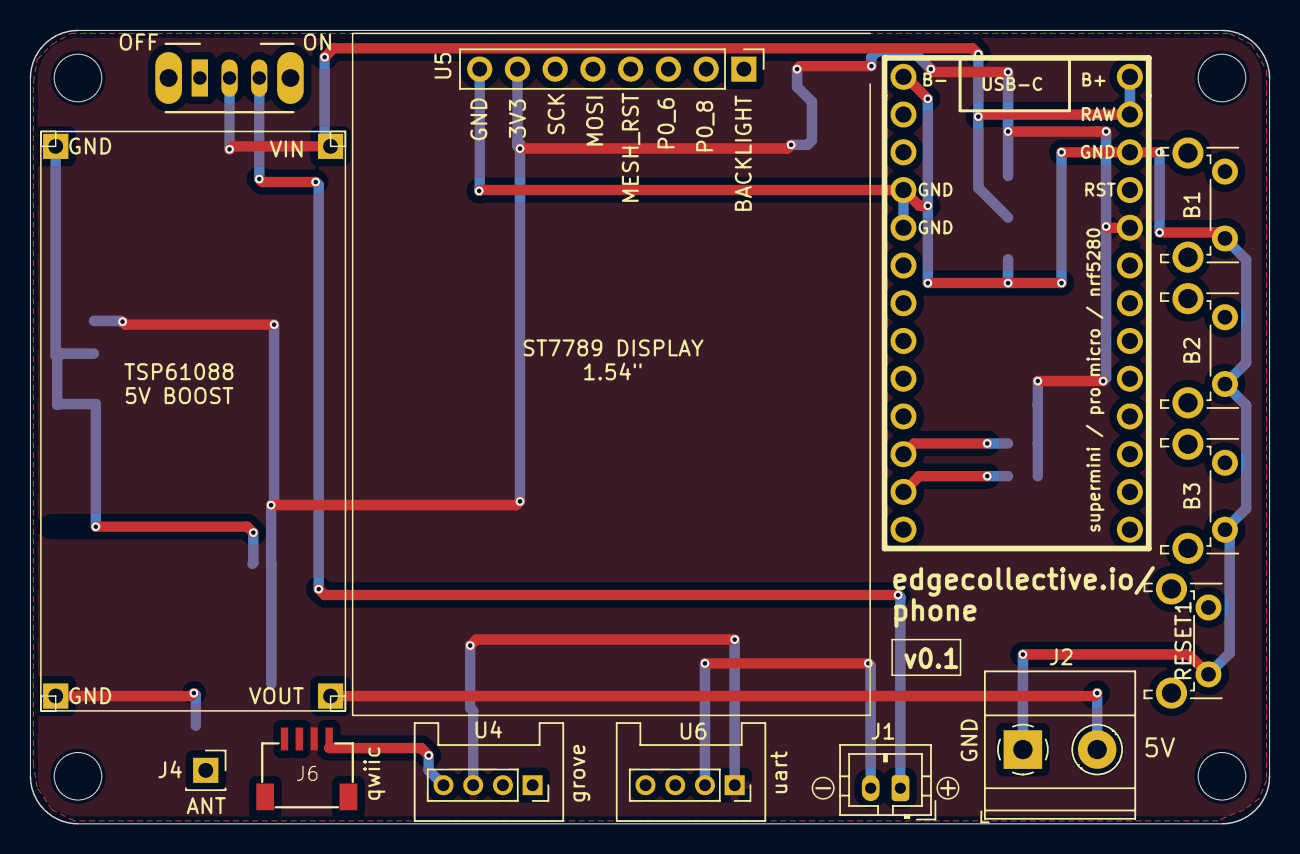
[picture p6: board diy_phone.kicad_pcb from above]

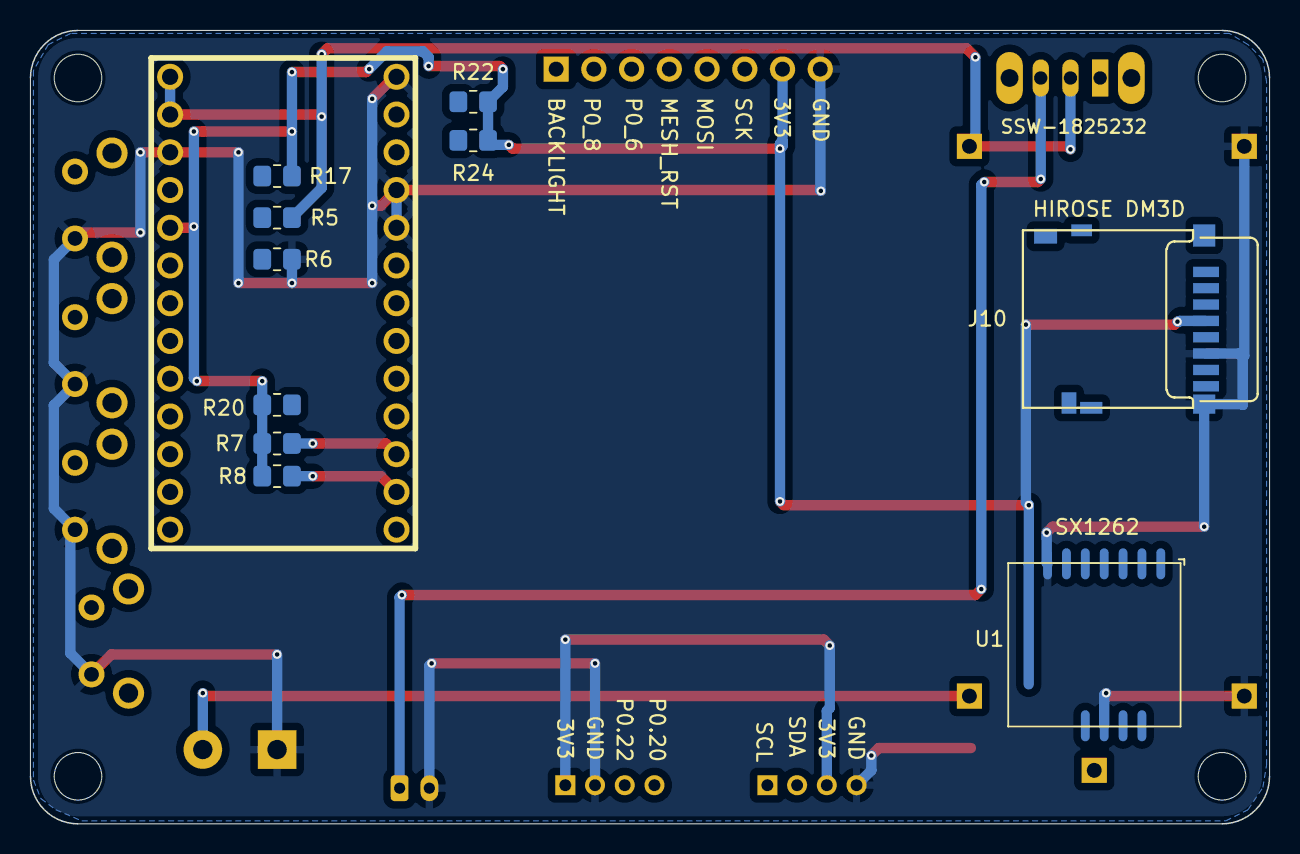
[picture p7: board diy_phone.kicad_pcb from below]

Board: 2 copper layers, 83.4 x 53.4 mm, 28 parts (10 on the bottom side), 25 nets.

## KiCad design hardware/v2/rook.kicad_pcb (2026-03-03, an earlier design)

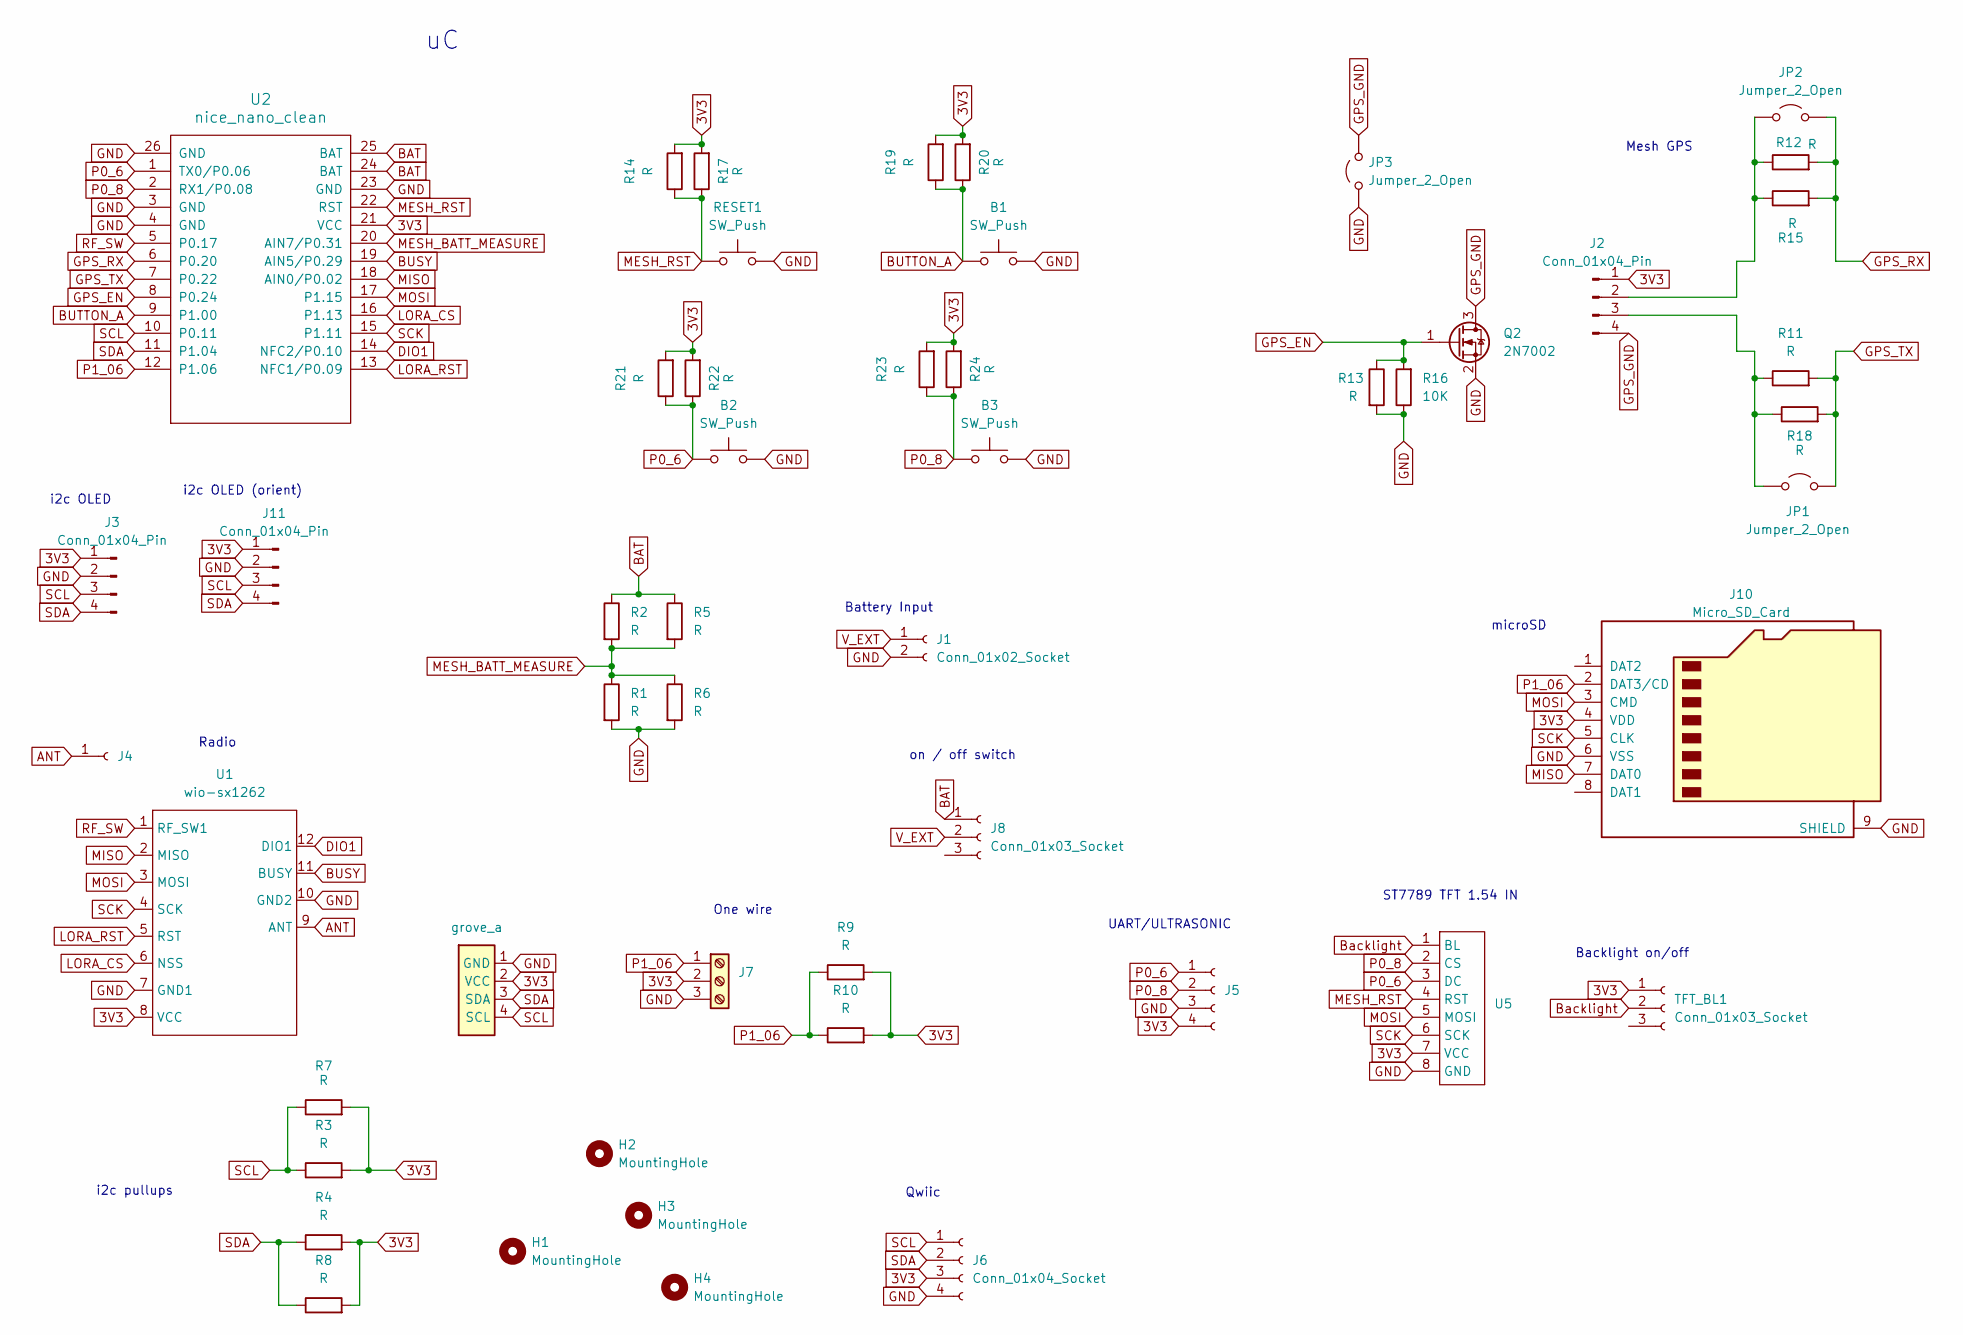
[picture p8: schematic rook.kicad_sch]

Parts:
B1, B2, B3: SW_Push; SW_Tactile_SPST_Angled_PTS645Vx31-2LFS
H1, H2, H3, H4: MountingHole; MountingHole_3.2mm_M3
J1: Conn_01x02_Socket; JST_PH_B2B-PH-K_1x02_P2.00mm_Vertical
J2: Conn_01x04_Pin; gps_ublox_blue
J3, J11: Conn_01x04_Pin; ssd1306_a
J4: Conn_01x01_Socket; PinSocket_1x01_P2.54mm_Vertical
J5: Conn_01x04_Socket; PinSocket_1x04_P2.54mm_Vertical
J6: Conn_01x04_Socket; JST_SH4_SKINNY
J7: Screw_Terminal_01x03; TerminalBlock_Phoenix_MKDS-1,5-3-5.08_1x03_P5.08mm_Horizont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
J8: Conn_01x03_Socket; SSW_1825232-1
J10: Micro_SD_Card; DM3D-SF_outline
JP1, JP2, JP3: Jumper_2_Open; SolderJumper-2_P1.3mm_Open_Pad1.0x1.5mm
Q2: 2N7002; SOT-23
R1, R2, R3, R4, R10, R11, R12, R13, R14, R19, R21, R23: R; R_Axial_DIN0207_L6.3mm_D2.5mm_P10.16mm_Horizontal
R5, R6, R7, R8, R9, R15, R17, R18, R20, R22, R24: R; R_0805_2012Metric_Pad1.20x1.40mm_HandSolder
R16: 10K; R_0805_2012Metric_Pad1.20x1.40mm_HandSolder
RESET1: SW_Push; SW_Tactile_SPST_Angled_PTS645Vx31-2LFS
TFT_BL1: Conn_01x03_Socket; SSW_1825232-1
U1: wio-sx1262; wio-sx1262-extended
U2: nice_nano_clean; nice_nano_cleanest
U4: grove_a
U5: st7789_154in_240x240

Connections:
3V3: J2.1, J3.1, J5.4, J6.3, J7.2, J10.4 (VDD), J11.1, R3.2, R4.2, R7.2, R8.2, R9.2, R10.2, R14.2, R17.2, R19.2, R20.2, R21.2, R22.2, R23.2, R24.2, TFT_BL1.1, U1.8 (VCC), U2.21 (VCC), U4.2 (VCC), U5.7 (VCC)
ANT: J4.1, U1.9 (ANT)
BAT: J8.1, R2.1, R5.1, U2.24 (BAT), U2.25 (BAT)
BUSY: U1.11 (BUSY), U2.19 (AIN5/P0.29)
BUTTON_A: B1.1, R19.1, R20.1, U2.9 (P1.00)
Backlight: TFT_BL1.2, U5.1 (BL)
DIO1: U1.12 (DIO1), U2.14 (NFC2/P0.10)
GND: B1.2, B2.2, B3.2, J1.2, J3.2, J5.3, J6.4, J7.3, J10.6 (VSS), J10.9 (SHIELD), J11.2, JP3.1 (A), Q2.2 (S), R1.2, R6.2, R13.2, R16.1, RESET1.2, U1.7 (GND1), U1.10 (GND2), U2.3 (GND), U2.4 (GND), U2.23 (GND), U2.26 (GND), U4.1 (GND), U5.8 (GND)
GPS_EN: Q2.1 (G), R13.1, R16.2, U2.8 (P0.24)
GPS_GND: J2.4, JP3.2 (B), Q2.3 (D)
GPS_RX: JP2.2 (B), R12.2, R15.2, U2.6 (P0.20)
GPS_TX: JP1.2 (B), R11.2, R18.2, U2.7 (P0.22)
LORA_CS: U1.6 (NSS), U2.16 (P1.13)
LORA_RST: U1.5 (RST), U2.13 (NFC1/P0.09)
MESH_BATT_MEASURE: R1.1, R2.2, R5.2, R6.1, U2.20 (AIN7/P0.31)
MESH_RST: R14.1, R17.1, RESET1.1, U2.22 (RST), U5.4 (RST)
MISO: J10.7 (DAT0), U1.2 (MISO), U2.18 (AIN0/P0.02)
MOSI: J10.3 (CMD), U1.3 (MOSI), U2.17 (P1.15), U5.5 (MOSI)
unnamed: J2.2, JP2.1 (A), R12.1, R15.1
unnamed: J2.3, JP1.1 (A), R11.1, R18.1
P0_6: B2.1, J5.1, R21.1, R22.1, U2.1 (TX0/P0.06), U5.3 (DC)
P0_8: B3.1, J5.2, R23.1, R24.1, U2.2 (RX1/P0.08), U5.2 (CS)
P1_06: J7.1, J10.2 (DAT3/CD), R9.1, R10.1, U2.12 (P1.06)
RF_SW: U1.1 (RF_SW1), U2.5 (P0.17)
SCK: J10.5 (CLK), U1.4 (SCK), U2.15 (P1.11), U5.6 (SCK)
SCL: J3.3, J6.1, J11.3, R3.1, R7.1, U2.10 (P0.11), U4.4 (SCL)
SDA: J3.4, J6.2, J11.4, R4.1, R8.1, U2.11 (P1.04), U4.3 (SDA)
V_EXT: J1.1, J8.2

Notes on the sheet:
microSD
Mesh GPS
ST7789 TFT 1.54 IN
Backlight on/off
on / off switch
One wire
i2c pullups
i2c OLED
Radio
UART/ULTRASONIC
i2c OLED (orient)
Battery Input
Qwiic

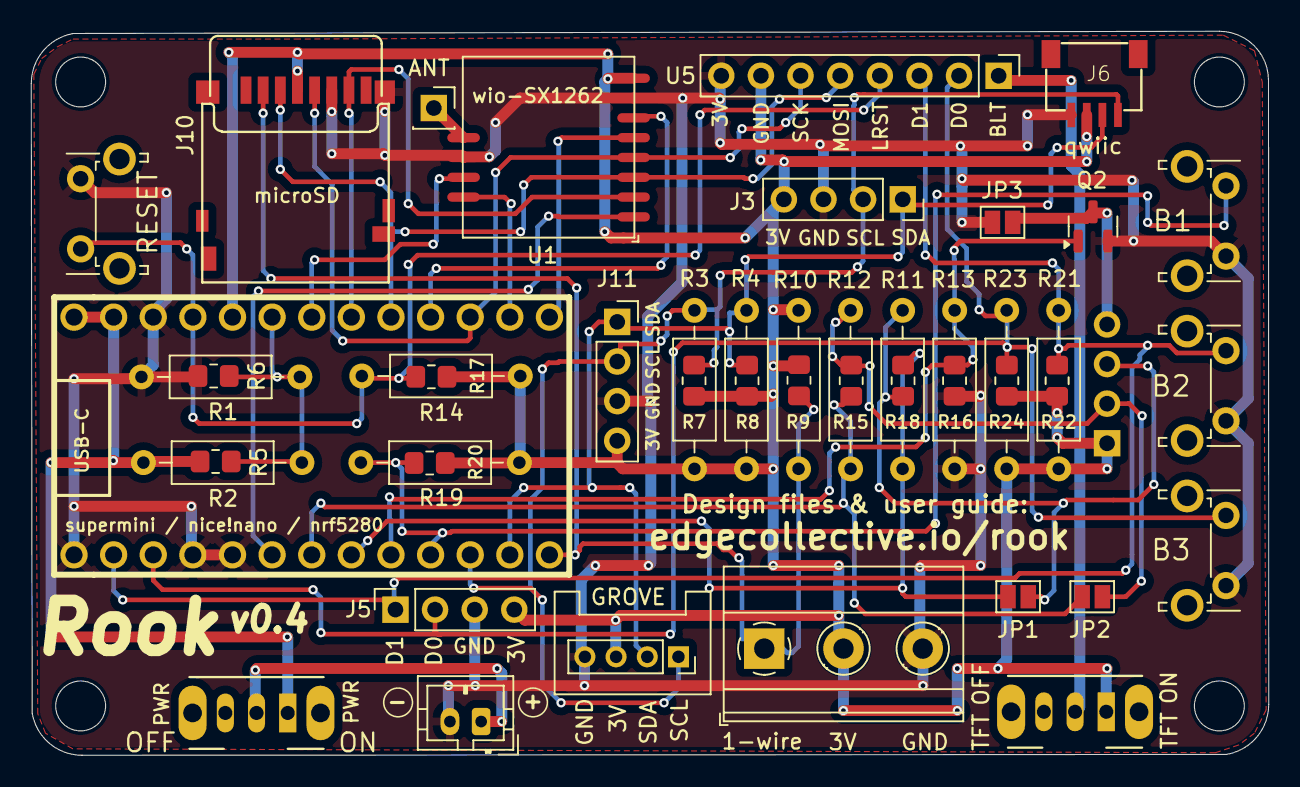
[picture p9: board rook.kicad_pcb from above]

Board: 2 copper layers, 79.3 x 46.4 mm, 51 parts (1 on the bottom side), 28 nets.

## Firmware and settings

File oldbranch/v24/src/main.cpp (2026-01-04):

/**************************************************************************
  DIY Phone v24 - Dynamic Canvas Sizing and Message Positioning
  Features: Display + SIM7600 + SD card SMS storage + I2C keyboard control + Address book name lookup + Full timestamps + Auto SMS deletion + Message threads
  Tests triggered by keyboard: 1=Signal, 2=AT Test, 3=SMS Check, 4=SD Test, 5=SMS Read, 6=Network, 7=Delete One-by-One, 8=Delete Bulk
  
  v24 Changes: 
  - Dynamic message canvas positioning based on inbox content
  - Adaptive canvas sizes based on actual contact count  
  - Messages sorted with latest at bottom
  - Auto-scroll to fill upper portion when messages don't fill canvas
 **************************************************************************/

#include <Arduino.h>
#include <Adafruit_GFX.h>    // Core graphics library
#include <Adafruit_ST7789.h> // Hardware-specific library for ST7789
#include <SPI.h>
#include <Wire.h>
#include <SdFat.h>
#include "SIM7600.h"

// Custom SPI bus definition
SPIClass customSPI(NRF_SPIM2, A1, A2, A0);  // MISO=A1, SCK=A2, MOSI=A0

// Pin definitions for ItsyBitsy nRF52840
#define TFT_CS        A3
#define TFT_RST        12 // Or set to -1 and connect to Arduino RESET pin
#define TFT_DC         A5

// SD card pin (using hardware SPI)
#define SD_CS_PIN     10

// I2C keyboard address
#define KEYBOARD_ADDR 0x5F

// Create display object with custom SPI bus
Adafruit_ST7789 tft = Adafruit_ST7789(&customSPI, TFT_CS, TFT_DC, TFT_RST);

// SIM7600 cellular module - using Serial1 (hardware UART)
SIM7600 cellular(&Serial1);

// SD card object
SdFat sd;

// UART buffer for line reading
String uartLineBuffer = "";

// Address book entry structure
struct AddressBookEntry {
  String phoneNumber;
  String name;
};

// SMS structure for inbox display with enhanced sorting
struct SMSInboxEntry {
  String sender;
  String senderDisplayName;  // Either phone number or contact name
  String time;
  String fullTime;           // Full timestamp for display
  String content;
  String filename;           // For sorting
  unsigned long timestampValue; // Numeric timestamp for proper sorting
};

// Address book and SMS inbox data
AddressBookEntry addressBook[100];
int addressBookCount = 0;
SMSInboxEntry smsInbox[50];
int smsInboxCount = 0;
int inboxScrollOffset = 0;
int inboxSelectedIndex = 0;  // Currently selected inbox entry (relative to scroll offset)
int messageScrollOffset = 0;       // Scroll position in message canvas
int currentInboxHeight = 100;      // Current height of inbox canvas (dynamic)
int currentMessageY = 142;         // Current Y position of message canvas (dynamic)
int currentMessageHeight = 95;     // Current height of message canvas (dynamic)

// Function declarations
void updateStatus(const char *text, uint16_t color);
void updateInbox();
void updateMessages();
void calculateCanvasSizes();
void updateSeparator();
void loadMessagesForContact(const String& senderNumber);
void loadAllMessagesForContact(const String& senderNumber);
void readUARTLines();
void handleKeyboard();
String getKeyName(uint8_t keyCode);
void runTest(int testNumber);
bool loadSMSInbox();
void sortSMSByTime();
void filterToUniqueContacts();
void handleNewSMSNotification(int smsIndex);
void addNewSMSToInbox(const String& filename);
bool deleteAllSMSIndividually();
bool deleteAllSMSWithStorageSelection();
bool loadAddressBook();
String lookupContactName(const String& phoneNumber);
unsigned long parseTimestamp(const String& timestamp);
int compareSMSByTime(const void* a, const void* b);
String formatDateWithoutYear(const String& timestamp);

// Canvas objects - 1-bit monochrome for maximum memory efficiency
GFXcanvas1 inbox_canvas(320, 100);  // Inbox canvas - height for 10 lines (10 pixels each)
GFXcanvas1 message_canvas(320, 95);  // Message canvas - reduced by 3 more pixels (240-inboxY-100-12-3 = 95)

#define statusY 10
#define inboxY 30
#define separatorY 130  // inboxY + 100 = 130
#define messageY 145    // separatorY + 12 + 3 = 145

void setup(void) {
  Serial.begin(115200);
  delay(2000); // Wait for serial connection
  Serial.println("=== DIY Phone v24 Starting ===");

  // Initialize custom SPI bus
  Serial.println("[DEBUG] Starting custom SPI initialization...");
  customSPI.begin();
  Serial.println("[DEBUG] Custom SPI initialized");

  // Initialize display
  Serial.println("[DEBUG] Starting display initialization...");
  tft.init(240, 320);
  tft.setRotation(3);
  tft.fillScreen(ST77XX_BLACK);
  
  Serial.println("[DEBUG] Display initialized");
  delay(500);
  Serial.println("[DEBUG] About to call updateStatus...");
  updateStatus("Display OK", ST77XX_GREEN);
  Serial.println("[DEBUG] Status updated");
  delay(500);
  
  // Initialize I2C for keyboard
  Serial.println("[DEBUG] Initializing I2C for keyboard...");
  Wire.begin();
  Serial.println("[DEBUG] I2C initialized for keyboard at address 0x5F");
  
  // Scan I2C bus to see what devices are present
  Serial.println("[DEBUG] Scanning I2C bus...");
  int devicesFound = 0;
  for (uint8_t address = 1; address < 127; address++) {
    Wire.beginTransmission(address);
    uint8_t error = Wire.endTransmission();
    
    if (error == 0) {
      Serial.print("[DEBUG] I2C device found at address 0x");
      if (address < 16) Serial.print("0");
      Serial.print(address, HEX);
      Serial.println();
      devicesFound++;
    }
  }
  
  if (devicesFound == 0) {
    Serial.println("[DEBUG] No I2C devices found on bus");
  } else {
    Serial.print("[DEBUG] Found ");
    Serial.print(devicesFound);
    Serial.println(" I2C devices");
  }
  
  // Test I2C connection with detailed debugging
  Serial.println("[DEBUG] Testing I2C keyboard connection...");
  Serial.print("[DEBUG] Requesting 1 byte from address 0x");
  Serial.println(KEYBOARD_ADDR, HEX);
  
  uint8_t bytesReceived = Wire.requestFrom(KEYBOARD_ADDR, 1);
  Serial.print("[DEBUG] Wire.requestFrom() returned: ");
  Serial.println(bytesReceived);
  
  Serial.print("[DEBUG] Wire.available(): ");
  Serial.println(Wire.available());
  
  if (Wire.available()) {
    uint8_t testData = Wire.read();
    Serial.print("[DEBUG] I2C keyboard test successful, received: 0x");
    Serial.print(testData, HEX);
    Serial.print(" (decimal: ");
    Serial.print(testData);
    Serial.println(")");
    updateStatus("Keyboard OK", ST77XX_GREEN);
  } else {
    Serial.println("[DEBUG] WARNING: No response from I2C keyboard");
    Serial.println("[DEBUG] This could mean:");
    Serial.println("[DEBUG] 1. Keyboard not connected");
    Serial.println("[DEBUG] 2. Wrong I2C address");
    Serial.println("[DEBUG] 3. I2C timing issue");
    updateStatus("Keyboard Warning", ST77XX_YELLOW);
  }
  
  // Check if there's any data left in buffer
  int remainingBytes = Wire.available();
  if (remainingBytes > 0) {
    Serial.print("[DEBUG] Additional bytes available: ");
    Serial.println(remainingBytes);
    while (Wire.available()) {
      uint8_t extraByte = Wire.read();
      Serial.print("[DEBUG] Extra byte: 0x");
      Serial.println(extraByte, HEX);
    }
  }
  
  delay(1000);

  // Initialize SD card
  Serial.println("[DEBUG] About to initialize SD card...");
  if (sd.begin(SD_CS_PIN, SD_SCK_MHZ(4))) {
    Serial.println("[DEBUG] SD card initialized");
    updateStatus("SD card OK", ST77XX_GREEN);
    
    // Test SD card by creating a test file
    Serial.println("[DEBUG] Testing SD card write...");
    FsFile testFile = sd.open("test.txt", O_WRITE | O_CREAT);
    if (testFile) {
      testFile.println("DIY Phone v19 Test");
      testFile.close();
      Serial.println("[DEBUG] SD card test file created successfully");
      updateStatus("SD test OK", ST77XX_GREEN);
    } else {
      Serial.println("[DEBUG] Failed to create SD test file");
      updateStatus("SD test failed", ST77XX_RED);
    }
  } else {
    Serial.println("[DEBUG] SD card initialization failed");
    updateStatus("SD card failed", ST77XX_RED);
  }
  Serial.println("[DEBUG] SD card initialization complete");
  delay(1000);

  // Load address book from SD card
  Serial.println("[DEBUG] Loading address book...");
  updateStatus("Loading contacts...", ST77XX_CYAN);
  loadAddressBook();
  Serial.println("[DEBUG] Address book loading complete");
  delay(500);

  // Configure Serial1 pins to match hardware: RX=A4, TX=D2
  Serial.println("[DEBUG] Configuring Serial1 pins...");
  Serial1.setPins(A4, 2);  // setPins(rx, tx)
  Serial.println("[DEBUG] Serial1 pins configured");
  
  // Note: UART buffer size increased via platformio.ini build_flags
  
  // Initialize SIM7600 at 115200 baud
  Serial.println("[DEBUG] Starting SIM7600 initialization...");
  if (cellular.begin(115200)) {
    Serial.println("[DEBUG] SIM7600 connected");
    updateStatus("SIM7600 connected", ST77XX_GREEN);
    
    // Enable caller ID
    Serial.println("[DEBUG] Enabling caller ID...");
    cellular.enableCallerID();
    Serial.println("[DEBUG] Caller ID enabled");
    
    // Check signal quality
    Serial.println("[DEBUG] Checking signal quality...");
    int signal = cellular.getSignalQuality();
    char signalText[32];
    snprintf(signalText, sizeof(signalText), "Signal: %d", signal);
    Serial.println(signalText);
    Serial.println("[DEBUG] Signal quality check complete");
    
  } else {
    Serial.println("[DEBUG] SIM7600 connection failed");
    updateStatus("SIM7600 failed", ST77XX_RED);
  }
  Serial.println("[DEBUG] SIM7600 initialization complete");
  
  // Skip SMS loading during setup to keep system responsive
  Serial.println("[DEBUG] Skipping SMS loading during setup for responsiveness");
  
  // Initialize empty canvases
  inbox_canvas.fillScreen(0);  // Black for 1-bit canvas
  message_canvas.fillScreen(0);  // Black for 1-bit canvas
  
  // Set default canvas sizes for empty state
  currentInboxHeight = 20;
  currentMessageY = inboxY + currentInboxHeight + 5;
  currentMessageHeight = 95;
  
  tft.drawBitmap(0, inboxY, inbox_canvas.getBuffer(), inbox_canvas.width(), currentInboxHeight, ST77XX_WHITE, ST77XX_BLACK);
  tft.drawBitmap(0, currentMessageY, message_canvas.getBuffer(), message_canvas.width(), currentMessageHeight, ST77XX_WHITE, ST77XX_BLACK);
  
  // Clear any remaining area below to prevent artifacts
  int clearAreaY = currentMessageY + currentMessageHeight;
  if (clearAreaY < 240) {
    tft.fillRect(0, clearAreaY, 320, 240 - clearAreaY, ST77XX_BLACK);
  }
  
  Serial.println("[DEBUG] Setup complete!");
  
  updateStatus("Ready - Press 5 for SMS", ST77XX_CYAN);
  Serial.println("===============================================");
  Serial.println("Setup complete - Press keyboard numbers 1-8:");
  Serial.println("1 = Signal Quality Test");
  Serial.println("2 = AT Command Test");
  Serial.println("3 = SMS Check & Store");
  Serial.println("4 = SD Card Test");
  Serial.println("5 = Read SMS Files (Load Inbox)");
  Serial.println("6 = Network Status");
  Serial.println("7 = Delete SMS One-by-One");
  Serial.println("8 = Delete All SMS (Bulk)");
  Serial.println("Down Arrow = Scroll inbox");
  Serial.println("===============================================");
}

void loop() {
  // Monitor UART from SIM7600
  readUARTLines();
  
  // Monitor keyboard
  handleKeyboard();
  
  delay(10);  // Small delay for stability
}

bool loadAddressBook() {
  Serial.println("=== Loading Address Book ===");
  
  addressBookCount = 0;
  
  // Try to open address book file (could be addressbook.txt, contacts.txt, etc.)
  FsFile addressFile = sd.open("addressbook.txt", O_READ);
  if (!addressFile) {
    addressFile = sd.open("contacts.txt", O_READ);
    if (!addressFile) {
      Serial.println("No address book file found (addressbook.txt or contacts.txt)");
      return false;
    }
  }
  
  Serial.println("Address book file found, loading contacts...");
  
  // Read address book entries
  while (addressFile.available() && addressBookCount < 100) {
    String line = "";
    while (addressFile.available()) {
      char c = addressFile.read();
      if (c == '\n' || c == '\r') {
        break;
      }
      line += c;
    }
    
    if (line.length() > 0) {
      // Parse line - expect format: "name,phone" or "phone,name"
      int commaPos = line.indexOf(',');
      if (commaPos != -1) {
        String part1 = line.substring(0, commaPos);
        String part2 = line.substring(commaPos + 1);
        part1.trim();
        part2.trim();
        
        // Determine which is phone number (starts with + or contains only digits)
        if (part1.startsWith("+") || (part1.length() > 5 && isDigit(part1[0]))) {
          addressBook[addressBookCount].phoneNumber = part1;
          addressBook[addressBookCount].name = part2;
        } else {
          addressBook[addressBookCount].phoneNumber = part2;
          addressBook[addressBookCount].name = part1;
        }
        
        Serial.print("Loaded contact: ");
        Serial.print(addressBook[addressBookCount].name);
        Serial.print(" -> ");
        Serial.println(addressBook[addressBookCount].phoneNumber);
        
        addressBookCount++;
      }
    }
  }
  
  addressFile.close();
  
  Serial.print("Loaded ");
  Serial.print(addressBookCount);
  Serial.println(" contacts");
  
  return addressBookCount > 0;
}

String lookupContactName(const String& phoneNumber) {
  Serial.print("[LOOKUP] Searching for: '");
  Serial.print(phoneNumber);
  Serial.print("' in ");
  Serial.print(addressBookCount);
  Serial.println(" contacts");
  
  // Clean the phone number for comparison (remove spaces, dashes, +, etc.)
  String cleanNumber = phoneNumber;
  cleanNumber.replace(" ", "");
  cleanNumber.replace("-", "");
  cleanNumber.replace("(", "");
  cleanNumber.replace(")", "");
  cleanNumber.replace("+", "");
  
  Serial.print("[LOOKUP] Cleaned number: '");
  Serial.print(cleanNumber);
  Serial.println("'");
  
  for (int i = 0; i < addressBookCount; i++) {
    String cleanBookNumber = addressBook[i].phoneNumber;
    cleanBookNumber.replace(" ", "");
    cleanBookNumber.replace("-", "");
    cleanBookNumber.replace("(", "");
    cleanBookNumber.replace(")", "");
    cleanBookNumber.replace("+", "");
    
    Serial.print("[LOOKUP] Checking contact ");
    Serial.print(i);
    Serial.print(": '");
    Serial.print(addressBook[i].name);
    Serial.print("' -> '");
    Serial.print(cleanBookNumber);
    Serial.println("'");
    
    // Try exact match first
    if (cleanNumber.equals(cleanBookNumber)) {
      Serial.print("[LOOKUP] EXACT MATCH found: ");
      Serial.println(addressBook[i].name);
      return addressBook[i].name;
    }
    
    // Try match without country code
    if (cleanNumber.length() > 10 && cleanBookNumber.length() == 10) {
      if (cleanNumber.endsWith(cleanBookNumber)) {
        Serial.print("[LOOKUP] PARTIAL MATCH (remove country code): ");
        Serial.println(addressBook[i].name);
        return addressBook[i].name;
      }
    }
    
    // Try match with country code added
    if (cleanNumber.length() == 10 && cleanBookNumber.length() > 10) {
      if (cleanBookNumber.endsWith(cleanNumber)) {
        Serial.print("[LOOKUP] PARTIAL MATCH (add country code): ");
        Serial.println(addressBook[i].name);
        return addressBook[i].name;
      }
    }
  }
  
  Serial.println("[LOOKUP] No match found, returning original number");
  // No match found, return the original phone number
  return phoneNumber;
}

unsigned long parseTimestamp(const String& timestamp) {
  // Parse timestamp format: "25/12/27,17:14:21-32"
  // Return seconds since epoch-like value for sorting
  
  int commaPos = timestamp.indexOf(',');
  if (commaPos == -1) return 0;
  
  String datePart = timestamp.substring(0, commaPos);
  String timePart = timestamp.substring(commaPos + 1);
  
  // Parse date: "25/12/27" (day/month/year)
  int day = 0, month = 0, year = 0;
  int slash1 = datePart.indexOf('/');
  int slash2 = datePart.lastIndexOf('/');
  if (slash1 != -1 && slash2 != -1 && slash1 != slash2) {
    day = datePart.substring(0, slash1).toInt();
    month = datePart.substring(slash1 + 1, slash2).toInt();
    year = datePart.substring(slash2 + 1).toInt();
    if (year < 50) year += 2000; // Assume 20xx
    else if (year < 100) year += 1900; // Assume 19xx
  }
  
  // Parse time: "17:14:21-32" (hour:min:sec-timezone)
  int hour = 0, minute = 0, second = 0;
  int dashPos = timePart.indexOf('-');
  if (dashPos != -1) {
    timePart = timePart.substring(0, dashPos);
  }
  
  int colon1 = timePart.indexOf(':');
  int colon2 = timePart.lastIndexOf(':');
  if (colon1 != -1 && colon2 != -1 && colon1 != colon2) {
    hour = timePart.substring(0, colon1).toInt();
    minute = timePart.substring(colon1 + 1, colon2).toInt();
    second = timePart.substring(colon2 + 1).toInt();
  }
  
  // Create a simple timestamp value (not actual epoch, but good for sorting)
  unsigned long timestampValue = 
    ((unsigned long)year) * 10000000000UL +
    ((unsigned long)month) * 100000000UL +
    ((unsigned long)day) * 1000000UL +
    ((unsigned long)hour) * 10000UL +
    ((unsigned long)minute) * 100UL +
    ((unsigned long)second);
    
  return timestampValue;
}

bool loadSMSInbox() {
  Serial.println("=== Loading SMS Inbox from SD Card ===");
  
  smsInboxCount = 0;
  inboxScrollOffset = 0;  // Reset scroll position
  inboxSelectedIndex = 0; // Reset selection to top
  
  updateStatus("Opening SD root dir", ST77XX_CYAN);
  FsFile root = sd.open("/");
  if (!root) {
    updateStatus("SD root open failed", ST77XX_RED);
    return false;
  }
  
  updateStatus("SD opened, reading files", ST77XX_CYAN);
  FsFile file;
  
  int fileCount = 0;
  while (file.openNext(&root, O_RDONLY) && smsInboxCount < 50 && fileCount < 200) { // Limit total files scanned
    fileCount++;
    char filename[64];
    file.getName(filename, sizeof(filename));
    
    if (fileCount % 10 == 0) {
      char statusMsg[32];
      snprintf(statusMsg, sizeof(statusMsg), "Checked %d files", fileCount);
      updateStatus(statusMsg, ST77XX_CYAN);
      delay(10); // Small delay to keep system responsive
      
      // Check for keyboard input during long operations
      handleKeyboard();
    }
    
    // Check if this is an SMS file (starts with "sms_")
    if (strncmp(filename, "sms_", 4) == 0) {
      Serial.print("Loading SMS file: ");
      Serial.println(filename);
      
      char statusMsg[32];
      snprintf(statusMsg, sizeof(statusMsg), "Found %d SMS files", smsInboxCount + 1);
      updateStatus(statusMsg, ST77XX_CYAN);
      
      // Parse SMS file content
      String lines[4];
      int lineCount = 0;
      
      // Read up to 4 lines from the file
      while (file.available() && lineCount < 4) {
        String line = "";
        while (file.available()) {
          char c = file.read();
          if (c == '\n' || c == '\r') {
            break;
          }
          line += c;
        }
        if (line.length() > 0) {
          lines[lineCount] = line;
          lineCount++;
        }
      }
      
      // Parse the lines if we have enough data
      if (lineCount >= 4) {
        smsInbox[smsInboxCount].sender = lines[0];
        smsInbox[smsInboxCount].sender.replace("From: ", "");
        
        smsInbox[smsInboxCount].time = lines[1];
        smsInbox[smsInboxCount].time.replace("Time: ", "");
        smsInbox[smsInboxCount].fullTime = formatDateWithoutYear(smsInbox[smsInboxCount].time);
        
        smsInbox[smsInboxCount].content = lines[3];
        smsInbox[smsInboxCount].content.replace("Content: ", "");
        
        smsInbox[smsInboxCount].filename = String(filename);
        
        // Parse timestamp for proper sorting
        smsInbox[smsInboxCount].timestampValue = parseTimestamp(smsInbox[smsInboxCount].time);
        
        // Look up contact name
        smsInbox[smsInboxCount].senderDisplayName = lookupContactName(smsInbox[smsInboxCount].sender);
        
        Serial.print("  From: ");
        Serial.print(smsInbox[smsInboxCount].senderDisplayName);
        Serial.print(" (");
        Serial.print(smsInbox[smsInboxCount].sender);
        Serial.print(") Time: ");
        Serial.print(smsInbox[smsInboxCount].time);
        Serial.print(" Content: ");
        Serial.println(smsInbox[smsInboxCount].content.substring(0, 30) + "...");
        
        smsInboxCount++;
      }
    }
    file.close();
  }
  root.close();
  
  char finalMsg[32];
  snprintf(finalMsg, sizeof(finalMsg), "Loaded %d SMS files", smsInboxCount);
  updateStatus(finalMsg, ST77XX_GREEN);
  
  Serial.print("Total SMS loaded into inbox: ");
  Serial.println(smsInboxCount);
  return smsInboxCount > 0;
}

void sortSMSByTime() {
  // Sort SMS messages by actual timestamp value (newest first)
  for (int i = 0; i < smsInboxCount - 1; i++) {
    for (int j = 0; j < smsInboxCount - i - 1; j++) {
      if (smsInbox[j].timestampValue < smsInbox[j + 1].timestampValue) {
        // Swap entries (newest first)
        SMSInboxEntry temp = smsInbox[j];
        smsInbox[j] = smsInbox[j + 1];
        smsInbox[j + 1] = temp;
      }
    }
  }
  Serial.println("SMS inbox sorted by timestamp (newest first)");
}
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

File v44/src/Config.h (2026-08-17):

// Config.h -- every pin, dimension and capacity in the phone, in one place.
#pragma once

#include <Arduino.h>

// ---------------------------------------------------------------- hardware
// ProMicro nRF52840. Pin numbers are Arduino pins; see promicromap.txt for
// the nRF52840 GPIO each one lands on.
namespace Pins {
  // TFT display, on SPIM2. MISO is unused by the ST7789 but the SPIClass
  // constructor requires a pin, so pin 6 is a placeholder.
  constexpr uint8_t TFT_MISO = 6;   // P1.00 (placeholder, unused)
  constexpr uint8_t TFT_SCK  = 9;   // P1.06
  constexpr uint8_t TFT_MOSI = 2;   // P0.17
  constexpr uint8_t TFT_CS   = 11;  // P0.10
  constexpr uint8_t TFT_DC   = 10;  // P0.09
  constexpr uint8_t TFT_RST  = 5;   // P0.24

  // SD card, on its own bus (SPIM3) so display traffic can't disturb it.
  constexpr uint8_t SD_MISO = 15;   // P0.02
  constexpr uint8_t SD_SCK  = 12;   // P1.11
  constexpr uint8_t SD_MOSI = 14;   // P1.15
  constexpr uint8_t SD_CS   = 13;   // P1.13

  // SIM7600 cellular modem, on Serial1.
  constexpr uint8_t MODEM_RX = 4;   // P0.22, MCU receives
  constexpr uint8_t MODEM_TX = 3;   // P0.20, MCU transmits

  // I2C keyboard uses the default Wire pins: SDA=8 (P1.04), SCL=7 (P0.11).
}

constexpr uint8_t  KEYBOARD_I2C_ADDR = 0x5F;
constexpr uint32_t MODEM_BAUD        = 115200;

// Used for displaying message times until the network reports the real local
// offset (AT+CCLK?). Minutes east of UTC: US Eastern is -240 in summer (EDT),
// -300 in winter (EST). Once network time sync works this only covers boot.
constexpr int16_t DEFAULT_TZ_MIN = -4 * 60;
constexpr uint32_t CONSOLE_BAUD      = 115200;

// ---------------------------------------------------------------- capacities
constexpr int MAX_CONTACTS        = 100;
constexpr int MAX_THREADS         = 100;  // >= MAX_CONTACTS so every contact is reachable
constexpr int MAX_THREAD_MESSAGES = 30;   // most recent messages held for the open thread
constexpr int MAX_COMPOSE_CHARS   = 160;
constexpr int MAX_SEARCH_CHARS    = 16;
constexpr int PREVIEW_CHARS       = 26;   // message preview shown in the contact row

// ---------------------------------------------------------------- screen
constexpr int SCREEN_W = 240;
constexpr int SCREEN_H = 240;

constexpr int CHAR_W  = 6;   // Adafruit_GFX built-in font at size 1
constexpr int LINE_H  = 10;

// Screen regions are defined by the UI in main.cpp; only the shared
// character metrics live here.

// ---------------------------------------------------------------- behaviour
constexpr uint32_t STATUS_REFRESH_MS = 5000;  // how often the RAM readout ticks

constexpr uint8_t SPEAKER_VOLUME_MAX = 5;  // AT+CLVL range
constexpr uint8_t MIC_GAIN_MAX       = 8;  // AT+CMICGAIN range
constexpr uint8_t SPEAKER_VOLUME_DEFAULT = 4;
constexpr uint8_t MIC_GAIN_DEFAULT       = 4;

// ---------------------------------------------------------------- keyboard
namespace Key {
  constexpr uint8_t Backspace = 0x08;
  constexpr uint8_t Tab       = 0x09;
  constexpr uint8_t Enter     = 0x0D;
  constexpr uint8_t Esc       = 0x1B;
  constexpr uint8_t Left      = 0xB4;
  constexpr uint8_t Up        = 0xB5;
  constexpr uint8_t Down      = 0xB6;
  constexpr uint8_t Right     = 0xB7;

  inline bool isPrintable(uint8_t k) { return k >= 32 && k <= 126; }
  inline bool isLetter(uint8_t k) {
    return (k >= 'A' && k <= 'Z') || (k >= 'a' && k <= 'z');
  }
}

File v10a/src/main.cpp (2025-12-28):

/**************************************************************************
  SIM7600 Cellular Phone Controller
  Converted from CircuitPython p26.py to C++
  Features: SMS, Voice Calls, Display UI, SD Storage, I2C Keyboard
 **************************************************************************/

#include <Arduino.h>
#include <SPI.h>
#include <Wire.h>
#include <SdFat.h>
#include <Adafruit_GFX.h>
#include <Adafruit_ST7789.h>

// Custom SPI bus for display
SPIClass customSPI(NRF_SPIM2, A1, A2, A0);  // MISO=A1, SCK=A2, MOSI=A0

// Display pin definitions
#define TFT_CS        A3
#define TFT_RST       12
#define TFT_DC        A5

// SD card pin definitions  
#define SD_CS         10

// UART for SIM7600 (D2=TX, A4=RX)
#define SIM_TX_PIN    2
#define SIM_RX_PIN    A4

// I2C keyboard address
#define KEYBOARD_ADDR 0x5F

// Display and storage objects
Adafruit_ST7789 tft = Adafruit_ST7789(&customSPI, TFT_CS, TFT_DC, TFT_RST);
SdFat SD;
File dataFile;

// UART buffer for SIM7600 communication
String uartLineBuffer = "";
String smsNotificationBuffer = "";

// Address book structure
struct Contact {
  String name;
  String number;
};

Contact addressBook[10];
int addressBookSize = 0;
int recipientIndex = 0;

// UI State Management
enum ViewState {
  VIEW_INBOX,
  VIEW_DETAIL, 
  VIEW_COMPOSE,
  VIEW_CALL,
  VIEW_THREAD,
  VIEW_INCOMING_CALL
};

ViewState currentView = VIEW_INBOX;
int selectedMessageIndex = 0;
int inboxScrollOffset = 0;
String composeMessage = "";
int selectedRecipientIndex = 0;
String manualNumberEntry = "";
bool recipientMode = false; // false=contacts, true=manual

// Call state
bool callInProgress = false;
String callStatus = "";
String callContactName = "";
unsigned long callStartTime = 0;
bool incomingCallActive = false;
String incomingCallerNumber = "";

// Message storage
struct SMSMessage {
  String sender;
  String timestamp;
  String content;
  String filename;
};

SMSMessage messagesList[20];
int messagesCount = 0;

// Display text buffers (simulating CircuitPython labels)
String displayLines[8];
String statusText = "";
String infoText = "";
String titleText = "INBOX";

// Keyboard input
uint8_t keyboardData = 0;
char lastKey = 0;

// Key definitions
#define KEY_UP     0xB5
#define KEY_DOWN   0xB6
#define KEY_LEFT   0xB4
#define KEY_RIGHT  0xB7
#define KEY_ENTER  0x0D
#define KEY_ESC    0x1B
#define KEY_BACK   0x08
#define KEY_SPACE  0x20
#define KEY_TAB    0x09

// Function declarations
void initializeSystem();
void loadAddressBook();
void saveAddressBook();
void setupDisplay();
void setupSDCard();
void setupUART();
void setupI2C();
String getKeyName(uint8_t keyCode);
String getViewName(ViewState view);

void handleKeyboard();
void processKeyInput(char key);
void readUARTLines();
void processUARTLine(String line);
void handleSMSNotification(String line);
void parseIncomingCall(String line);

void displayInbox();
void displayMessageDetail();
void displayCompose();
void displayCallScreen();
void displayThreadView();
void displayIncomingCall();
void updateDisplay();
void clearDisplay();

void scrollInboxUp();
void scrollInboxDown();
void selectMessage();
void startReply();
void startNewCompose();
void sendMessage();
void makeCall();
void answerCall();
void rejectCall();

void getMessages();
void parseAndStoreSMS(String data);
void storeSMSToSD(String sender, String timestamp, String content);
void loadSMSFromSD();
String formatSender(String sender);
String formatTimestamp(String timestamp);

void sendATCommand(String command);
String readATResponse(int timeout = 1000);
void initializeSIM();

void setup() {
  Serial.begin(115200);
  Serial.println("Starting SIM7600 Phone Controller...");
  
  initializeSystem();
  loadAddressBook();
  setupDisplay();
  setupSDCard();
  setupUART();
  setupI2C();
  
  // Initialize SIM7600
  delay(2000);
  initializeSIM();
  
  // Load existing messages and display inbox
  loadSMSFromSD();
  displayInbox();
  
  Serial.println("System ready!");
}

void loop() {
  // Read and process UART data from SIM7600
  readUARTLines();
  
  // Handle keyboard input
  handleKeyboard();
  
  // Update display if needed
  updateDisplay();
  
  // Handle call timing if in progress
  if (callInProgress && callStatus == "connected") {
    // Update call duration every second
    if (millis() - callStartTime >= 1000) {
      callStartTime = millis();
      if (currentView == VIEW_CALL) {
        displayCallScreen(); // Refresh display with updated duration
      }
    }
  }
  
  delay(50); // Small delay for stability
}

void initializeSystem() {
  // Initialize address book with default contacts
  addressBook[0] = {"Don (voip)", "16512524765"};
  addressBook[1] = {"Don (iphone)", "17813230341"};
  addressBook[2] = {"Liz", "16174299144"};
  addressBookSize = 3;
}

void setupDisplay() {
  Serial.println("[DEBUG] Initializing display...");
  
  // Initialize custom SPI bus
  customSPI.begin();
  Serial.println("[DEBUG] Custom SPI bus initialized");
  
  // Initialize display
  tft.init(320, 240);  // 320x240 display with rotation
  tft.setRotation(1);  // Landscape mode
  tft.fillScreen(ST77XX_BLACK);
  Serial.println("[DEBUG] Display initialized (320x240, landscape)");
  
  // Display startup message
  tft.setTextColor(ST77XX_GREEN);
  tft.setTextSize(2);
  tft.setCursor(10, 100);
  tft.println("SIM7600 Phone");
  tft.setCursor(10, 130);
  tft.println("Starting up...");
  
  Serial.println("[DEBUG] Display startup message shown");
  delay(1000);
}

void setupSDCard() {
  Serial.println("[DEBUG] Initializing SD card...");
  
  if (!SD.begin(SD_CS)) {
    Serial.println("[DEBUG] ERROR: SD card initialization failed!");
    // Show error on display
    tft.fillScreen(ST77XX_BLACK);
    tft.setTextColor(ST77XX_RED);
    tft.setCursor(10, 100);
    tft.println("SD Card Error!");
    delay(2000);
    return;
  }
  
  Serial.println("[DEBUG] SD card initialized successfully");
  
  // Test SD card with a simple write/read
  dataFile = SD.open("test.txt", FILE_WRITE);
  if (dataFile) {
    dataFile.println("Hello world!");
    dataFile.close();
    Serial.println("[DEBUG] SD card test write successful");
  } else {
    Serial.println("[DEBUG] WARNING: SD card test write failed");
  }
}

void setupUART() {
  // Initialize UART for SIM7600 communication
  Serial.println("[DEBUG] Initializing UART for SIM7600...");
  
  // Configure Serial1 to use specific pins for SIM7600
  // TX = D2, RX = A4
  Serial1.setPins(A4, 2);  // setPins(rx, tx)
  Serial1.begin(115200);
  
  Serial.println("[DEBUG] UART initialized at 115200 baud (TX=D2, RX=A4)");
}
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
